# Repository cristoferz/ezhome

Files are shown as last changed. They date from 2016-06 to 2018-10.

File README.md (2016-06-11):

# ezHome Project 

This is the home for the ezHome team's development.

### Project status

For now, the project is on the beginning so there's not much to talk about.
We are developing the basis for customization capabilitys, communication standarts and somethings like that. 

More details can be founded on Issues.

## See also ##
[Project Pieces](PROJECT_PIECES.md)

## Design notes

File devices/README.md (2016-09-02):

# ezHome Project Devices
Devices are the phisical endpoints for ezHome project. Their are responsible for 
interacting with home devices like lights, light switches, doors, buzzer and so on.

Actually only one kind of device is in development, but is possible to implement
others as needed. This kind is based on Arduino devices and is capable of controlling
digital inputs and outputs. It can also be expanded to use PWM ports and Analog ports.

See also:

* [JSON Ladder Format](JSON_LADDER.md)
* [Device Communication Protocol](PROTOCOL.md)

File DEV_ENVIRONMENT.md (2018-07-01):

# Developer guide: getting your environment set up

## Web Development
1. Install node, with at least version 4.6.1
1. Run `npm install -g angular-cli` to install angular-cli
1. On folder `local-site/frontend` run `npm install`

To bring up a local server, run `ng serve`. This automatically watch for changes and rebuild. The browser should refresh automatically when changes are made.

To build the components in dev mode, run `ng build`. To build the components in release mode, run `ng build --prod`.

## Controller Development
Controller is developed is Netbeans. Install at least Netbeans 8.

Is recommended to have ant installed and on path to allow command line compilation. This is mainly necessary for a release build, for development Netbeans 
compilation will serve well.

## Database Development
EzHome database is a PostgreSQL. 

There is no templates already defined for database.  

## Devices Development
Devices are developed with Arduino IDE. Install at least version 1.6.9. 

## Build a release
Is necessary to have all environments configured. This is needed because of make commands that rebuild all structures before packaging.

```

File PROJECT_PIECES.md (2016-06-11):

# Project pieces of ezHome Project #

The ezHome Project is composed of many pieces that have to work together to the main goal. This pieces involves many different technologies so its necessary to define the bounds for each one.

This pieces are:

* **[Controller](controller/README.md)**: The main coordinator of the project, is responsible for connected every other parts. Is developed in Java SE;
* **[Local configuration site](local-site/README.md)**: Run over the controller. Is the local user interface for ezHome instalation and configuration. Is developed on Angular 2 with angular-material2. As the backend runs over the controller, it is developed on Java SE;
* **[Devices](devices/README.md)**: Are the electrical parts of the project. Mainly are used Arduinos for the job, but other device types can be accepted;
* **[Remote controlling site](remote-site/README.md)**: Is the remote web-site responsible for controlling and monitoring the home. It also controls activation and remote backups of configurations and communications with mobile platforms. It is develop on PHP and stored with postgresql;
* **[Mobile App](mobile/README.md)**: Mobile aplication for remote controlling the Home. Can communicate with remote controlling site or local configuration site, depending on used network. Is developed with ionic2;

As the project is on the beginning, the technologies are only suggestions and can change if there is a good reason for it.

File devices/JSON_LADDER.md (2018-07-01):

# JSON Ladder
JSON Ladder is the base language used to program ezHome Project compatible devices 
with the logics implemented on ezHome Project. Is basically a translation of the 
Ladder Language to a JSON format that is used for store configurations on local and remote databases.
Above is a basic example of implementation:

    { "program":
        [ { "serie": [
                { "Parallel": [
                { "serie": [
                    { "NO": 10 },
                    { "Parallel": [
                        { "serie": [
                            { "FallingEdge": 100 }
                        ] },
                        { "serie": [
                            { "RisingEdge": 101 }
                        ] }
                    ] }
                ] }
                ] },
                { "SetReset": { "address": 4, "reset": 4} }
            ] },
            { "serie": [
                { "Parallel": [
                { "serie": [
                    { "NO": 11 },
                    { "Parallel": [
                        { "serie": [
                            { "FallingEdge": 104 }
                        ] },
                        { "serie": [
                            { "RisingEdge": 105 }
                        ] }
                    ] }
                ] },
                { "serie": [
                    { "NO": 5 },
                    { "FallingEdge": 106 }
                ] }
                ] },
                { "SetReset": { "address": 2, "reset": 2} }
            ] },
        ] }

It is composed by the following parts:

## Flow tags
Flow tags are the tags used to define the interactions between the instructions on ladder engine. They do not perform any tasks on devices outputs, but define the flow of rung conditions between instructions.

## Program
The base of JSON Ladder. Its used only once on a JSON Ladder program and just define the root of the logics. Its similar to the "parallel" instructions discussed later on purpose, but is the only tag that can be used on program root.

Contains an array of series to be executed by JSON Engine.

     { "program": [ 
        { "serie": [ ... ] },
        { "serie": [ ... ] }
      ]}

## Serie
Represents a serie of instructions processed in a serial form on JSON Engine. 
Its represented by an array of instructions to processed in a serial form, each one passing a *rungCondition* to the next one and using this value on its own logics.

    { "serie": [
       { ... },
       { ... }
    ]}

## Instructions
Unlike the flow tags, instructions are intended for interactions with memory addresses, device ports or simply to interact with rungCondition to the next instruction.

Basically, every instruction receives a rungCondition and passes a new rungCondition to the next instruction. The simplest instructions are NO and NC, discussed later.

### Contact NO and NC
Contact NO and NC are the simplest instructions with input on a Ladder logics. As the ladder borns based on eletrical relays, they are representation of an eletrical switch.
NO represents a "Normally Open" switch and NC represents a "Normally Closed" switch. So the only difference between then are the inverted results, so "NO = !NC" is a good representation. 

On JSON Ladder, both contacts need an "interaction value", and this can be represented with a "boolean value".

Boolean values can be a constant value, like "true" or "false" or a representing address. As on a device an memory address can represent a phisical port or just a memory address,
Boolean Values can be used for phisical or memory interactions, allowing great flexibility to the instruction.

The constant form of a boolean value is represented by a boolean value on JSON format, as following examples:

    { "NO": true }
    { "NC": false }

Is not very logical to use constant values for contacts as the example, but boolean values are used for others purposes so its important to know that is possible.

Other way to use the boolean values are assigning to then a memory address that can be a phisical port or just a memory value. This can be done by passing the integer value of desired address, like following:

    { "NO": 0 }
    { "NC": 108 }

This assigns address 0 (normally phisical port 2) and 108 (just a memory address) to contacts.

The main objective of contact instructions are they rungCondition result. They are always based on 2 values:
* Incoming rungCondition: or the rungCondition that comes from prior instruction
* Their input value: as represented by assigned address or constant value

This way, we can represent the resulting rungCondition for NO as:

    <Incoming rungCondition> && <Input value>

And for NC as:

    <Incoming rungCondition> && !<Input value>

As you can see, the only difference is the invertion of the Input value. Incoming rungCondition always affect the resulting rungCondition the same way.

### Coil
Represents an Output on Ladder logics.

Basically, a Coil instruction reflects the incoming rungCondition on their Output Address, that can be a phisical output or memory value. The resulting rungCondition is exactly the same value as input rungCondition.
Normally Coil is the final instruction for a serie, but its not mandatory.

On JSON Ladder, Coil representation is like following:

    { "Coil": 1 }

As an coil always sets the value of their output destination, necessarily only one coil can be 
assigned to each address. This is not a restriction. If more than one coil are assigned to the 
same address, the last one on the engine flow will override their value before it reflect a 
phisical response. Probabily an unexpected behavior.

### Parallel
Parallel is a instruction, but can also be seen as an flow tag. 
It represents a *fork* on ladder logics, allowing parallel series to be executed inside a serie
and resulting *rungCondition* being united in an "or" logics.

    { "Parallel": [
       { "serie": [ ... ] },
       { "serie": [ ... ] }
    ]} 

In a "program" tag, resulting rungCondition is just discarded and next serie is initialized
with a "true" value, not affecting the next serie. On a Parallel instruction, all inner 
series resulting rungCondition are combined on a "or logics" like the following:

    serie1 | serie2 | serie3 | ...

Resulting rungCondition is passed to the next instruction on the outer serie. Following is an example of 2 Contact NO interacting with 1 Coil, using a parallel:

    { "serie": [
       { "Parallel": [
          { "serie": [
             { "NO": 1 }
          ]},
          { "serie": [
             { "NO": 2 }
          ]}
       ] },
       { "Coil": 3 }
    } 

In this example, any of the NO that have an high level, will put a high level on the Coil. 
This is because the "OR" logics of the Parallel instruction.

The series on the Parallel are the same as the series on a Program, so its possible to do anything on then, as incluing Parallel inside another Parallel. 
Is possible to use Parallel instructions on as many inner levels as necessary.       

### Edges
The edge type of instructions are the type of instruction that detects an edge on signal 
represented by rungCondition. There are 2 types of edges: Rising and Falling. They detect an 
variation on signal from high to low (FallingEge) or low to high (RisingEdge). 

The effect of such variation is a "true" value on preceding rungCondition for just on engine cycle. This is 
different from NO and NC contacts. They keep the value for as long as the signal is high or low. The edges 
just but a high level to represent the variation of the signal an just for one cycle. 
No mather what signal is before an edge, the edges only pass a high signal just one cicle when 
the expected edge is detected, turning back to low signal.

The edges have no directly output. They unique purpose is to set the preceding rungCondition as the edge is detected. 
So, they will never appear alone in a serie. There is no restriction to this, but its meaningless to do this.

The edges needs, for their internal logics, a boolean memory address. In this case, the memory address cannot be a
phisical port from device. There is no restriction to do this, but this will cause an unexpected behavior, as the port 
will interact with the internal address of the edge. The purpose of this address is to "save" the "old state" of signal
across engine cycles. This is necessary because the edge always compares the current state with the "old state", and this 
have to be saved across engine cycles.

With this is mind, there is no use for the edge address except for the edge itself.

Examples of both edge representation are the following:

    { "FallingEdge": 100 }
    { "RisingEdge": 101 }

A practical example is explore after we understand the SetReset instruction.

### SetReset
SetReset instruction are maded for, as the name says, set or reset the value of a memory address
of device. We can understand set as put "true" on this address and reset as put "false" on this 
address. Its a single instruction because its possible to define their state at runtime, inverting 
their result.

This instruction easily work in conjuction with edges, but there is no restriction to the use with others 
instructions. This instruction take 2 parameters:
* address: The output address. That the address that will be set or reset;
* reset: A boolean value that represents if the instruction will set or reset the output;

As the reset parameter is a boolean value, it can be a constant value (true or false) or a memory address
containing the expected behavior. 

An example of usage is as following:

    { "SetReset": {
       "address": 0,
       "reset": true
    }}

Or:

    { "SetReset": {
       "address": 0,
       "reset": 100
    }}    

This represents the both forms of SetReset instruction. First one use the constant form, where the value
of address 0 is always set to false when a rungCondition of true precedes the instuction. On the second form,
the value of true or false depends on value of the memory address 100. The value of the address is inverted 
accordingly to the name "reset" so, if the value of address is true (reset), the value setted is false and if
the value is false (not reset), the value setted it true.

A very useful case of use of the runtime reset value is a "auto reversing configuration". An example is as 
following:

    { "SetReset": {
       "address": 0,
       "reset": 0
    }} 

As the same address is used for both output and reset values, for every cycle that rungCondition is true the 
value of address 0 is inverted, passing from true to false or false to true. This is very useful if combined 
with an edge instruction, as the example above:

    { "serie": [
       { "NO": 1 },
       { "FallingEdge": 100 },
       { "SetReset": {
          "address": 0,
          "reset": 0
       }}
    ]} 

Consider that a push button is connected to address 1 and a LED is connected to address 0. With this configuration
for every click on the button, the light turn off or turn on and keeps this state until the next interaction with 
the button.

### NumericValues
At this point is necessary for complete understanding of the following instructions that we known a new structure:
the NumericValues. Until now, we are using just boolean values, either constants or not, but never more than this.
For the next instructions are necessary to understand that is possible to use NumericValues.

NumericValues, as the same says, are basically numbers, but we have some differences on the address system. A numeric 
address of value 18 is not the same address as a boolean address of value 18. This is because the address system for
numeric values are completely isolated for boolean addresses. This happens because of natures of values and phisical
ports of devices. Boolean address are linked to digital ports of device and Numeric address are linked to analog ports
of device. As an example, lets take the Arduino MEGA 2560. They have 54 digital ports and 16 analog ports, that are 
completely different ports. So, the boolean addresses from 0 to 52 (thats because ports 0 and 1 are useless) are linked
to the digital ports. And, the numeric addresses from 0 to 15 are linked to analog ports. The preceding addresses are 
just memory addresses, having no phisical interaction.

NumericValue have 2 forms of representation:
* Constant: having static value like above:

    { "value": 200 }

* Variable: assigned to a numeric memory address like above:

     { "address": 18 }

Once assigned to an analog port the value will reflect in the analog value for the port.

### Timers
Timers are the time based instructions for the JSON Ladder. The logics are based on 3 values, specified on definition:
* setpointValue: specifies the time in milliseconds elapsed for a timer be considered done.
* doneAddress: a boolean address that represents the done state for the timer.
* elapsedAddress: a numeric address to store the elapsed time for the timer.

With the same variables, a timer can be one of 2 types:
* TimerOn 
   
   Every time the preceding rungCondition is true the timer start counting time, until achieve the setpointValue. During 
   this time, doneAddress keeps a false value, elapsedAddress keep the time passed until the true condition and resulting
   rungCondition return false. Once the setpointValue is achieved, doneAddress gains a true value and rungCondition returns 
   true.

* TimerOff

   Every time the preceding rungCondition is true the timer start counting time, until achieve the setpointValue. During 
   this time, doneAddress keeps a true value, elapsedAddress keep the time passed until the false condition and resulting
   rungCondition return true. Once the setpointValue is achieved, doneAddress gains a false value and rungCondition returns 
   false.

If the running condition for the timer (true for TimerOn and false for TimerOff) changes, the timer resets immediatelly and 
elapsedTime returns to zero. 

An example of usage of TimerOn is as following:

    { "serie": [
       { "NO": 0 },
       { "TimerOn": {
          "setpointValue": 2000,
          "doneAddress": 1,
          "elapsedAddress": 18
       }},
       { "Coil": 2 }
    ]}
     
In this example, the contact NO commands the execution of Timer, as their control the preceding rungCondition. The Timer is 
configured for a 2s delay (2000ms), with doneAddress configured for address 1 and elapsedAddress configured for numeric 
address 18. A Coil assigned to address 2 is connected to the resulting rungCondition.

The logic is interpreted as follows:
Once the address 0 has a high value the timer will start running. During 2s the rungCondition reflects no alteration. 
If during this time the address 0 goes to an low value, the timer resets and the output will never change. Otherwise, if 
passes the 2 seconds and address 0 keeps the high value, then doneAddress will change to true and resulting rungCondition too. 
This stays like this for as long as the address 0 keeps the high value. Once the change to low value, immediatelly doneAddress 
and resulting rungCondition goes low too, no delay is applied this way.

TimerOff have a similar aproach, but with inverted values. Timer starts with a low value and reset with a high value.

Some considerations about parameters of timers:
* setpointValue can use both constants and variable values. A change during the timer execution will affect the result of timer 
without reseting him.
* doneAddress and resulting rungCondition always have the same value. Because of internal logics of the timer is necessary to 
specify an address, but is not necessary to use him.
* elapsedAddress can be used for reading, but take care with writings. A write on this address can cause unexpected behaviors. 
A mistake easy to take is try to use an address of an analog port. This will cause very strange results, and dificulty to find 
the problem. That because every cycle of engine will override the value if the analog value of the phisical port, and or the 
timer never ends, or ends very fast, depending on values of setpointValue. Anyway, of course this will not be the expected result.

### Counters
Counters are the most complex structures for now. Counters are instructions that uses the preceding rungCondition edge for autoincrement 
or autodecrement their values, according to their type (either count up or down). Their basic implementation is examplified above:

    { "Counter": {
       "countDown": false,
       "setpointValue": {
          "value": 10
       },
       "resetValue": 100,
       "doneAddress": 101,
       "countAddress": 18,
       "oneshotStateAddress": 102
    }} 

With this basics, this are the explanations about all the parameters:
* countDown: sets the timer as a count up or down. Its always a constant value so, its not possible to change at runtime.
* setpointValue: defines the value that the counter is considered "done". Explanations about what is "done" are maded above.
* resetValue: defines the boolean value that resets the counter. Can be a constant or variable
* doneAddress: boolean address that identify a counter as done. Similar to Timers this also reflects the resulting rungCondition
* countAddress: numeric address that stores the current count value.
* oneshotStateAddress: as the counters act like an edge, this is the address for the internal edge control

One simple explanation for counters is that they are an edge with a math add operation. But they do a little more than this. They 
controls a setpointValue, doneAddress and a reset operation in only one instruction. Lets explain this by parts. First of all the 
doneAddress and rungCondition. For our first example we have a count up counter (countDown: false), with a setpoint of 10. Lets put 
more instructions to be more clear:

    { "serie": [
       { "NO": 0 },
       { "Counter": {
          "countDown": false,
          "setpointValue": {
             "value": 10
          },
          "resetValue": 100,
          "doneAddress": 101,
          "countAddress": 18,
          "oneshotStateAddress": 102
       }},
       { "Coil": 1 }
    ]}  

In this example lets think we have a push button on address 0 and a LED on address 1.

At the start of program, we have the LED turn off, and the counter at 0. So, if we click 5 times on the button, nothing realy 
happens, just the internal counter goes to 5 and the LED still off. If click more 5 times, than the counter goes to 10 and 
setpointValue is hit so the rungCondition goes to true together with doneAddress and finally the LED turn on.

If at any time you read the countAddress you will have the counter value, so now we have the value of 10.

But, our LED is now turn on and there is no way to turn it off. That because differently from timers, counters do not 
autoreset at any condition. The only way to autoreset a counter is will a pulse on resetValue. If you keep the resetValue 
constantly on true, the counter will reset every cycle and never autoincrement their values.

If will implement another serie with the example above, together with our first example, will can reset your counter:

    { "serie": [
       { "NO": 2 },
       { "Coil": 100 }
    ]}

With a button connected to address 2, a click on it will reset the counter. while you keep the button pushed, the counter
never increment, they keep reseting.

### Math Operators
The counters are very useful for lots of situations, but their use is very specific as a counter. 
Sometimes is necessary to make some math operations with values. For this kind of situations there is the "MathOperation"
instruction. There 5 kind of math operations implemented by this instruction, they are (with their representation):
* ADD: +
* SUBTRACT: -
* MULTIPLY: *
* DIVIDE: /
* CHOOSE: #

They are self explanatory with the exception of the CHOOSE one. They are bettter explained above.

An example of MathOperation follows:

    { "MathOperation": {
       "type": "*",
       "operator1": {
          "address": 0
       },
       "operator2": {
          "value": 2
       },
       "resultAddress": {
          "address": 18
       }
    }}

This example shows a MathOperation with the MULTIPLY type. The result is that the value read from address 0, on operator1, 
is multiplied by 2, as the operator2 and the result is stored on numeric address 18. So the parameters explanation follows:

* type: the operator for the math operation. Can be one of: +,-,*,/,#
* operator1: a NumericValue for the first operator
* operator2: a NumericValue for the second operator
* resultAddress: a NumericAddress to store the operation result.

Math operations can use analog inputs, counters variables, timers elapsedAddress or any others numeric values as their 
operators. Is possible to use the same address on operators and resultAddress at the same instruction. One example is an
autoincrement on a numeric address, as follows:

    { "MathOperation": {
       "type": "+",
       "operator1": {
          "address": 18
       },
       "operator2": {
          "value": 1
       },
       "resultAddress": {
          "address": 18
       }
    }} 

This instruction will increment on the numeric value of address 18 every time the preceding rungCondition is true. 
But take care. The operation is done every cycle that the rungCondition is true, so if you put a NO contact before and
the user clicks the button, lots of cycle will passes during the high value of the button, incrementing the value lots 
of times. To prevent this, its common to use edges before the MathOperation, asuring that only one cycle will perform 
the operation per click.

A not self explanatory MathOperation is the CHOOSE type. But is a very simple one. Basically they choose the value to 
put on resulting address based on preceding rungCondition. If the rungCondition is false, then the operator1 value is 
putted on resultAddress, if true the value of operator2 is putted. Is a little different from the others because a edge 
will not serve well as a preceding instruction in most cases. 

The last thing to consider is the resulting rungCondition. They are not affected by MathOperation. So, if the preceding 
rungCondition is true, the resulting will be true and vice versa.

### Math Comparators
Math comparators are the "if" on Ladder logics for numeric values. Their objective is just affect the resulting 
rungCondition, not altering any memory addresses. An example of usage follows:

    { "Comparator": {
       "type": ">=",
       "value1": {
          "address": 0
       },
       "value2": {
          "value": 2
       }
    }}

Their parameter explanation follows:
* type: type of comparation. Can be one of: ==,>,>=,<,<=,!=
* value1: first value of comparation
* value2: second value of comparation

The type are all self explanatory and the logics can be read as follows:

    rungCondition = rungCondition && (value1 <type> value2)

Or as the example before:

    rungCondition = rungCondition && ([address 0] >= 2)

As you can see the operation always depends on preceding rungCondition. If they are false, the result is false and 
the instruction is not even processed. Otherwise, is processed and the result is the new rungCondition.

The example show a comparation of type >= of the value readed from address 0 (probabily an analog port) between the 
constant 2. If the value of the port is greater or equals 2, the resulting rungCondition will be true, otherwise false
respecting the preceding rungCondition too.

### External Devices
Sometimes is necessary to use external devices and sensors connected to ezHome. This devices are threated by an especific
instruction called "extDevice". Each external device has its own implementation, so theirs descriptions follow.

#### Temperature sensors
Some temperature sensor uses OneWire protocol to communicate to arduino. DS18B20 is an example of this. An example of 
instruction follows:

    { "TemperatureSensor": {
       "address": 4, 
       "idValue": "1234567890ABCDEF",
       "readDelay": { "value": 10000 },
       "elapsedAddress": 10,
       "outputAddress": 100,
       "failAddress": 5
    }}

The logics for this type of sensors is based on the following values, with explanation about each:
* address: Identifies the phisical port where the sensor is connected. In this case, is possible (and recommended) that 
many sensors are connected to the same port, but is possible to connect in other ports. In the specific case of DS18B20, 
is necessary a pull-up resistor of 4K7 to function. 
* idValue: Identifies the sensor on the bus. This value is unique per sensor, so its necessary to identify what sensor 
you are using. On the end of this session is some explanation on how to do this.
* readDelay: Specifies the delay between readings to the sensor. Other cycles assumes te last readed value. As reading 
sensor values causes some delay on whole device cycle, is recommended to reduce the reading frequency to as lower as you 
can, avoiding some interference on others logics.
* elapsedAddress: Specifies the address to keep the elapsed time between last read. Have no real use for logics.
* outputAddress: Address where readed values is stored and keeped until next read.
* failAddress: Address to indicates a fail on reading to sensor, usually because the sensor with specified address is not 
present on the port. In the case of failure, the output value will set to -127. 

The rungCondition for this instruction is true only on read cycles, as an alert of read.

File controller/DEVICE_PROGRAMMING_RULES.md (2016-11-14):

## Parts of device versions

### Version
Version is a set of modules and connections that defines the behavior of a device. Also a version is specific for a device type,
such as Arduino MEGA or UNO. This is needed because of phisical differences between then. 

### Modules
Modules is basically a group of inputs and output that defines a logic of interactions between then. This inputs and outputs
can be phisical or a connection with another module as specified above.

### Connections
As the name says, connections is the connection between different modules or different port of the same module. As a rule, 
every connection receives one, and only one, input that is always an output from a module. A connection can have multiple outputs,
that is always used as input from a module, either another or the same as the input of connection.

### Types of inputs/outputs (I/O)
There is three types of inputs/outputs that can be used in ezHome Devices:
* DIGITAL: Accepts only 2 possible values high and low, or translating to logics, is a boolean I/O;
* ANALOGIC: Is a numeric I/O, oscilating their voltage phisically and numeric value logically;
* PWM: Phisically is also a digital port, but logically is a numeric I/O. This specific type can only be used in phisical ports, 
and not on connections because they are processed by devices.

Connections also have the same type as I/Os. This is necessary because only ports of the same type can be connected. Only a 
module can "transform" an I/O from one type to another.

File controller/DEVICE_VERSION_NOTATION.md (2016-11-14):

# Device Version Notation
This document describes the programming language for ezHome devices, to be compiled and loaded on each device. 

# Modules
The main part of Device Version are the modules. Modules defines the electrical behavior and interactions between each
of his ports. All definition of a module has to be compatible with module configuration definition.

A version are a set of modules that have connections between then. 
An example of a module definition follows:

```
{
   "class": "br.com.ezhome.standard.DigitalInputModule",
   "name": "Kitchen outside door switch",
   "ports": [
      {
         "portType": "input",
         "phisicalAddress": 1
      },
      {
         "portType": "output",
         "connectionIndex": 1
      }
   ]
}
```

Above is a description of each parameter of the module.

## Class
The class attribute of a module is used by compiler to identify what module he are working on. All definition are loaded
based on class of a module.

The class is the full name of the class that defines him, as the example above:

```
"class": "br.com.ezhome.standard.modules.DigitalInputModule",
```

If the class specified on parameter is not registered a ClassNotFoundException will throws.

## Name
Name is the description of a module. This attribute is just for users to identify what module we are talking about.
The name can be any string and have no effect among the behavior of the module. An example follows:

```
"name": "Kitchen outside door switch",
```

## Ports
Ports are the inputs and outputs of a module. 

```
{
   "portType": "input",
   "phisicalAddress": 1
}
```

Ports are based on Port Types from Module Definition and can be of 2 types.

### PhisicalAddress
Are the ports connected to a phisical address of a device. The address specifies the phisical port of device. The definition
is simple and follows

```
"phisicalAddress": 1
```

Where "1" is the desired address.

### Connection
Connections, as the name says, are used to connect a module to anothers. On a module the connection is specified just by an
integer index. This is enough to create a new connection. 

```
"connectionIndex": 1
```

All module ports that use the same connectionIndex is considered connected with each other. But there's one restriction on this.

A connection can have only one input, from connection optics. From module optics, a connection INPUT is a module OUTPUT. 
This is necessary to preserve the logics of connections. If it was possible to connect two or more inputs on a single connection
the behavior of this connection will depend on the sequence of device logic cycle, something that is not controlled by the user. 

# Example
Here we have a example of a lightning controller.

```
{ 
   "modules": [ 
      {
         "class": "br.com.ezhome.standard.modules.DigitalInputModule",
         "name": "Kitchen switch",
         "ports": [
            {
               "portType": "input",
               "phisicalAddress": 0
            },
            {
               "portType": "output",
               "connectionIndex": 1
            }
         ]
      },
      {
         "class": "br.com.ezhome.standard.modules.DigitalOutputModule",
         "name": "Kitchen Light",
         "ports": [
            {
               "portType": "input",
               "connectionIndex": 3
            },
            {
               "portType": "output",
               "phisicalAddress": 3 
            },
         ]
      },
      {
         "class": "br.com.ezhome.standard.modules.LightningModule",
         "name": "Kitchen Light Controller",
         "ports": [
            {
               "portType": "input",
               "connectionIndex": 1
            },
            {
               "portType": "output",
               "connectionIndex": 3
            }
         ]
      }   
   ]
}
```

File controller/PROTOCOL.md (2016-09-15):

# ezHome Controller Communication Protocol #
## Activation and Login functions
### Validate activation
Returns activation state for this controller

    GET    /activation/validate

### Activate device
Activates controller with remote site

    POST   /activation/activate

### Login
Generates a token for access

    POST   /login/token              

----
## Serial ports
### List ports
Lists all serial ports available to controller

    GET    /config/serialPort?connected=<value>&portName=<value>

Params:

| Name | Required | Values | Description |
|---|---|---|---|
| connected | false | Boolean | Filter only ports on specified state |
| portName | false | String | Filter only specified port |

Response:

    {
        "serialPorts": [
            {
                "connected": true,
                "versionId": "0000000000000000",
                "currentOwner": "self",
                "portName": "/dev/ttyUSB0",
                "runtimeId": "0123456789ABCDEFFEDCBA9876543210",
                "deviceId": 1
            },
            {
                "connected": false,
                "portName": "/dev/ttyUSB0"
            }
        ]
    }

### Connect
Try to connect an ezHome device on port

    POST   /config/serialPort        

    { "portName": "/dev/ttyUSB0" }

Response:

    { "success": true }
    
### Disconnect   
Disconnect ezHome device on port, if available

    DELETE /config/serialPort        

### Scan
Makes a manual scan on serialPorts

    POST   /config/serialPort/scan    

### Enable/disable Auto-Scan
Enable/Disable autoscan on serial ports

    POST   /config/serialPort/autoScan 

----
## Device
### List devices
Lists configured devices

    GET    /config/device            

### Insert a new device
Insert a new device, creating a new UID

    POST   /config/device            

### Updates a device
Update device data, keeping UID

    PUT    /config/device            

### Delete a device
Inactivate device

    DELETE /config/device            

### Send command
Sends a command to device

    POST   /config/device/send

### Initializes device
Initializes device, burning firmware, creating a new UID for device and cleaning EEPROM.

    POST   /config/device/initialize 

### Upgrade firmware version
Upgrades firmware version keeping UID for device

    POST   /config/device/upgrade

### Upload program do device
Sends a program version to device

    POST   /config/device/upload     

### Config-reset
Sends a program version to device

    POST   /config/device/upload     

### Factory-reset
Resets all configs and program from device
    
    POST   /config/device/factory-reset

### Resets device
Resets device

    POST   /config/device/reset

### Pause
Pause the device logics and disable all outputs

    POST   /config/device/pause

### Resume
Resume the device logics

    POST   /config/device/resume     

### Information
Reads device information

    GET    /config/device/information

### Device-config
Reads device config

    GET    /config/device/device-config

### Read Boolean
Reads a boolean value from device

    GET    /config/device/readBoolean 

### List Models
Lists all available models of device

    GET    /config/device/model      

Response:

    {
      "models": [
         {
            "name": "Arduino MEGA 2560",
            "model_id": 2,
            "model_cod": "MEGA",
            "thumbnail": "/images/arduino_mega.jpg"
         },
         {
            "name": "Arduino NANO",
            "model_id": 3,
            "model_cod": "NANO",
            "thumbnail": "/images/arduino_nano.jpg"
         }
      ]
    }    

----
## Program
### List Programs
Lists program versions available and where they are applied

    GET    /config/device/program

### Insert Program
Creates a new version of program

    POST   /config/device/program

### Delete Program
Deletes a program version

    DELETE /config/device/program

## Devices ##
### List ###
List devices and serial ports available to the controller. Connected devices 
will return runtimeId and versionId, as a way to recognize the device independant 
of phisical port connected.  

#### Request ####
    GET /device/list
    
#### Response ####
    {
        "devices": [
            {
                "connected": true,
                "versionId": "0000000000000000",
                "currentOwner": "self",
                "name": "/dev/ttyUSB0",
                "runtimeId": "0123456789ABCDEFFEDCBA9876543210"
            },
            {
                "connected": false,
                "name": "/dev/ttyUSB0"
            }
        ]
    }

-------
### Connect ###
Connect to a device on specified serial port by **portName** parameter. 

#### Request ####
    POST /device/connect
    
    {
        "portName": "/dev/ttyUSB0"
    }
    
#### Response ####
On successfull connection:

    {
        "success": true
    }

On connection failure:

    {
        "success": false,
        "message": "gnu.io.NoSuchPortException"
    }
    
-------    
### Disconnect ###
Disconnect from device specified by **portName** parameter.

#### Request ####
    POST /device/disconnect
    
    {
        "portName": "/dev/ttyUSB0"
    }
    
#### Response ####
On successfull connection:

    {
        "success": true
    }

On connection failure:

    {
        "success": false,
        "message": "Invalid port"
    }   
    
-------
### Upload ###
Upload firmware for specified **portName**. If there is a valid
device on port, his firmware will be updated, otherwise is just
burned the new firmware.

Current configs loaded to device are preserved on proccess.

#### Request ####
    POST /device/upload
    
    { 
        "portName": "/dev/ttyUSB0",
        "model": "MEGA"
    }

#### Response ####
    {
        "result": "\navrdude: AVR device initialized and ready to accept instructions\navrdude: Device signature = 0x1e9801\navrdude: reading input file \"/tmp/ezHome-2103596859514401669.hex\"\navrdude: writing flash (20666 bytes):\navrdude: 20666 bytes of flash written\navrdude: verifying flash memory against /tmp/ezHome-2103596859514401669.hex:\navrdude: load data flash data from input file /tmp/ezHome-2103596859514401669.hex:\navrdude: input file /tmp/ezHome-2103596859514401669.hex contains 20666 bytes\navrdude: reading on-chip flash data:\navrdude: verifying ...\navrdude: 20666 bytes of flash verified\n\navrdude done.  Thank you.\n\n",
        "success": true
    }
    
------
### Send ###
Sends a **command** to especified **portName** and gets the result.

#### Request ####
    POST /device/send
    
    { 
        "portName": "/dev/ttyUSB0",
        "command": "runtime-id"
    }
    
#### Response ####
    {
       "success": true,
       "result": "RuntimeId=00000000000000000000000000000000"
    }
    
------

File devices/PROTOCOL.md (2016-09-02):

# Devices Communication Protocol for ezHome Project
This document provides protocol definition for devices used on ezHome Project. 
This protocol will be used on communications via serial port between devices and ezHome Controller.

## Table of contents
1. [Communication Standards](#markdown-header-communication-standards)
    1. [Send messages](#markdown-header-send-messages)
    1. [Received Messages](#markdown-header-received-messages)
1. [Query Functions](#markdown-header-query-functions)
    1. [Information](#markdown-header-information-query)
    1. [Device Config](#markdown-header-device-config-query)
    1. [Status](#markdown-header-status-query)
    1. [RuntimeId](#markdown-header-runtimeid-query)
    1. [VersionId](#markdown-header-versionid-query)
    1. [Read Boolean](#markdown-header-read-boolean)
    1. [Read Numeric](#markdown-header-read-numeric)
1. [Command Functions](#markdown-header-command-functions)
    1. [Factory Reset](#markdown-header-factory-reset)
    1. [Config Reset](#markdown-header-config-reset)
    1. [Config Output](#markdown-header-config-output)
    1. [Config PWM](#markdown-header-config-pwm)
    1. [Start](#markdown-header-start)
    1. [Stop](#markdown-header-stop)
    1. [Write Boolean](#markdown-header-write-boolean)
    1. [Write Numeric](#markdown-header-write-numeric)
1. [Program Functions](#markdown-header-program-functions)
    1. [Program Function Steps](#markdown-header-program-function-steps)

----    

## Communication Standards 
Messages of communication protocol have 2 types:
1. Send messages
1. Received messages

### Send Messages
These are the messages sended from controller to device. Every sended message waits for a response, 
confirming that sended command is executed.

They have 2 main formats:
* Normal messages: are the most common messages between both parts. 
Basically are a single line command preceded by a <End-Of-Line> character. Ex.:

       runtime-id 

* Programming messages: This special type of message is designed to be used only for device programation. 
This is necessary because of nature of sended data, as they are binary and cannot respect the format of a basic message. 
These messages are better described above.

### Received Messages
These are the messages sended from device to controller. There are 2 kinds of this messages:
* Response messages: this is a response to a sended message or command. 
As the messages can have many lines, every response message have a finish string. This finish string is a line with only **EOM**.

Example of response message:

    RuntimeId=1234567890876542
    EOM
    
* Status messages: this are the messages sended from device to controller to report an event that occurs on 
device that is not a response to a sended message. An example is a port state that can vary based on a light switch.
This kind of message are always single-lined, so there's no need of a finish string.

Example of status message:

    IS=1
    
## Query Functions
Query are operations used to query informations from device. Informations can be states of addresses, 
number of ports, runtimeId, version etc.

### Information query
Information returns data about loaded firmware, protocol version and available space on device to be 
used by the program.

Example of information request:

    information
    
Example of response:

    ezHome=0.1
    Protocol Version=1.0
    Booleans=1024
    Numerics=96
    Strings=0
    Max Program Size=3750
    Current Program Size=50
    EOM

This examples is a response from an Arduino Mega device. It is composed of several parts. They are:
* ezHome: indicates the firmwareVersion of ezHome device.
* Protocol Version: are the protocol version used by this device. 
Generally this are compatible with firmwareVersion
* Booleans: Number of boolean variables that can be used on this device
* Numerics: Number of numeric variables that can be used on this device
* String: Number of string variables that can be used on this device
* Max Program Size: returns that maximum program size that can be loaded on this device. 
It depends directly on EEPROM size of device.
* Current Program Size: return the size of current program loaded on device.
* EOM: the finish string

### Device Config Query
Device config query returns the device model and actual port configurations for this device. 

Example of request:

    device-config
    
Partial example of response:
    
    Device Name=Arduino
    pin2, 0, output
    pin3, 1, output
    pin4, 2, input
    ...
    pin53, 51, input
    A0, 0, analogInput
    A1, 1, analogInput
    ...
    A15, 15, analogInput
    EOM

This is a response from an Arduino Mega device. This response is composed of following parts:
* Device Name: Returns the device name
* Digital ports: Current configuration for digital ports. Are composed of 3 parts
    1. pin**X**: identifies the phisical pin on arduino
    1. address: represents the address (integer) used to access the state of this port
    1. mode: current mode defined for this port. Can be *input*, *output* or *pwm*. 
Analog ports can be *analogInput* or *analogOutput*
* EOM: finish string

### Status query
Status query function returns if the device is running or paused.
Devices can paused their engine by command.

Example of request:

    status
    
Example of response:

    Running=true
    EOM
    
### RuntimeId query
RuntimeId is the unique identification number for a device. Is used by controller to know on what 
serial port each device is connected and to control what versions can be used.
This information is also included on startup message.

Example of request:

    runtime-id
    
Example of response:

    RuntimeId=0123456789ABCDEFFEDCBA9876543210
    EOM
    
### VersionId query
VersionId is the unique identification number for a program version loaded into a device. 
This can assures that a expected version of program is loaded on device. Every program version
must create a new unique versionId.

Example of request:

    version-id
    
Example of response:

    RuntimeVersionId=0123456789ABCDEFFEDCBA9876543210
    EOM
    
### Read Boolean
Reads boolean state for given address on device. Address can be a port address or memory addresses. 

Example of request:

    read b 5
    
Example of response:

    1
    EOM
    
This response indicates that the address 5, which in this case is port 3, has a high level.

### Read Numeric
No numeric implementations are ready yet.

## Command Functions
Command functions are used to interact with device, changing states of addresses, port modes etc.

### Factory Reset
Factory reset is a master reset function for device. It cleans program and resets modes of all ports.
It also cleans RuntimeId and VersionId, so device loses its references.

Example of request:

    factory-reset
    
Example of response:
    
    Success=true
    EOM
    
### Config Reset
Config reset restore all ports to their initial states. 
Initial states of digital ports are Input mode and on analog are analogInput mode. 
Config-reset is actually the only way to change a port from output mode to input mode.

Example of request:

    config-reset
    
Example of response:

    Success=true
    EOM
    
### Config Output
Config output command defines a port as output. This configuration is writed on EEPROM, 
so it can only be changed by config-reset command.

Example of request:

    config-output 2
    
Example of response:

    Success=true
    EOM
    
This request configures phisical pin 2 on arduino to be an output port.

### Config PWM
Config PWM command defines a port as PWM Output. 

Example of request:

    config-pwm 4
    
Example of success response:

    Success=true
    EOM
    
Example of error response:
    
    Error=Not a valid PWM pin: 4
    EOM
    
As not all ports from a device can be configured as a PWM output an error can be throw if a invalid
port is given.    

### Start
Start command controls the running state of device engine. As the name suggests, it start the engine 
processing and the logics of program will be applied. Ports will respect the logics of the program.

Example of request:

    start
    
Example of response:
   
    Success=true
    EOM
    
### Stop
Stop command controls the running state of device engine. As the name suggests, it stops the engine 
processing and the logics of program will not be applied. All outputs are put on LOW state.

Example of request:

    stop
    
Example of response:
   
    Success=true
    EOM
    
### Write Boolean
Write boolean command function set a boolean value to specified address. 

Example of request:

    write b 2 1
    
Example of response:

    EOM
    
This request sets the boolean value of address 2 (in this case is pin 4 of arduino) to be at high level.     

Ps.: *This function cannot assure that this value will be preserved, just sets the current state. 
This could be overwriten by program engine on the next running cycle so realy works on 
address that are designed to be externally seted.*

### Write Numeric
No numeric implementations are ready yet.

## Program Functions
Program functions are specifically designed for program upload to device. There are 2 types of program
function:
* Download: Sends program to device, stoping engine. This function stops the engine at download beginning and starts at 
the end, so the ports can switch states during proccess
* Patch: Sends program to device, without stoping engine. This function download the new program without 
stoping the engine, so there's a risk of anomalous behaviors on big program changes.

### Program Function Steps
As the program function are more complex, their are composed of 2 pairs of request/response, as described
above:

**Header message:** informs to device the size of the program that will be send. This prepared the device
to receive full program;

Example of request:
    
    download 50
    
Response:

    Success=true
    Bytes=50
    EOM
    
This confirms that 50 bytes will be sended.

**Body message:** Transmits the program itself. As the total bytes is defined by header message the device
reads the amount of bytes specified putting directly into program memory. At the end the program is writen
on device EEPROM. 

The format used to send the program to device is based on [JSON Ladder format](JSON_LADDER.md) and its convertion to binary format is better described [here](JSON_LADDER_BINARY_CONVERSION.md).

Response:

    Success=true
    Bytes=50
    EOM
    
This confirms that the 50 bytes specified by program is received and writed on device's EEPROM.

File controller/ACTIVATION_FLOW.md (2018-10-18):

# ezHome Controller activation flow
This flow describes the process of activation for each controller and the security protocol used for comunication with remote server asuring maximum security for both sides.

## Local private and public key
The first step after instalation of ezHome controller is the generation of public and private keys. This is done internally by ezHome Security Manager and
this keys are stored only locally with the controller. The private key can never be transmited to another device, as this can destroy all the security process. 
Public keys are transmitted as needed.

## Certificate Signing Request (CSR)
After the generation of keys, next is to generate the CSR or Certificate Signing Request. This is needed for ezHome remote servers generate a certificate.
This request includes data about your controller and necessary keys for the certificate generation. 

## ezHome CA (Certificate Authority)
The ezHome CA is the main Certication Authority responsible for all controller certificates. This is de CA for all certificates generated by CSRs transmitted.

## Certificate generation
The CSR are now transmitted to ezHome remote servers and the servers are responsible for the generation of a secure and unique certificate that will be returned.
After that, the controller is just identified by its certificate and no other data is necessary.

## Communications
After all process done, all communications between controller and ezHome remote server are done via SSL (https) using both server and client certificates, based on 
ezHome CA. This asures criptografic data.

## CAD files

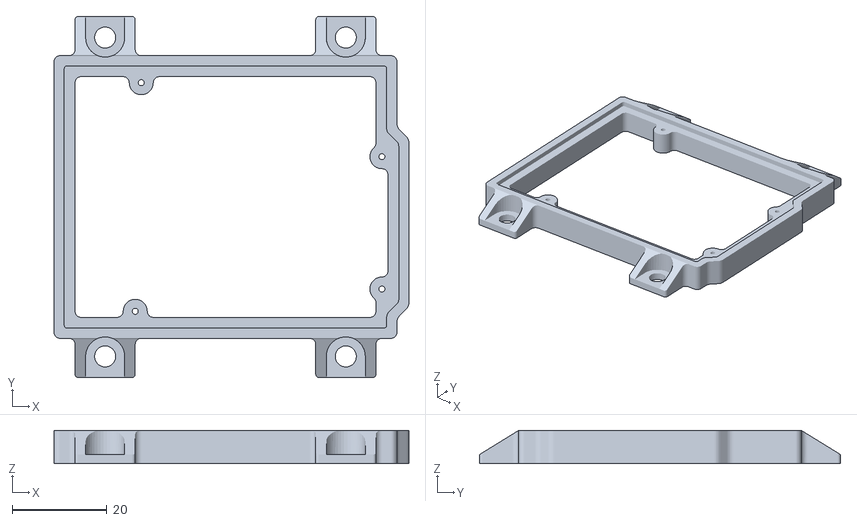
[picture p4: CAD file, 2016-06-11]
hardware/boxes/raspberry/UNO_R2_MOUNT.STL
74.9 x 76.2 x 6.99

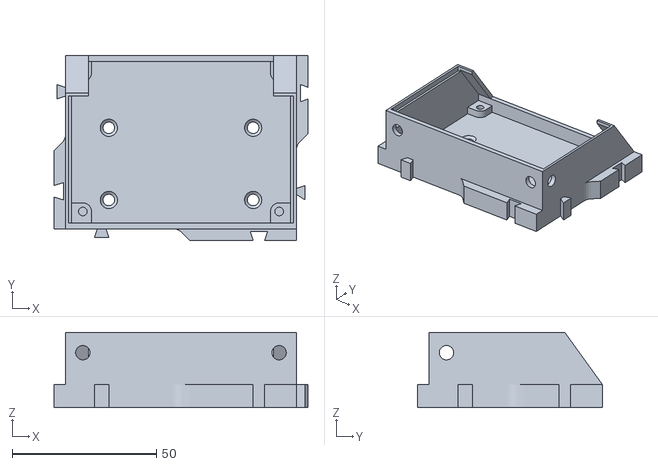
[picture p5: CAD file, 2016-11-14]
hardware/boxes/Relays/SupportV3-Box.stl
88.0 x 64.0 x 26.0

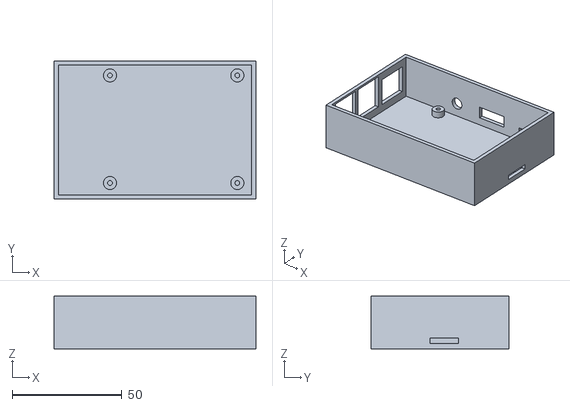
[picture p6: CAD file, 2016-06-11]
hardware/boxes/v1/test/teste02.stl
92.0 x 63.0 x 24.0

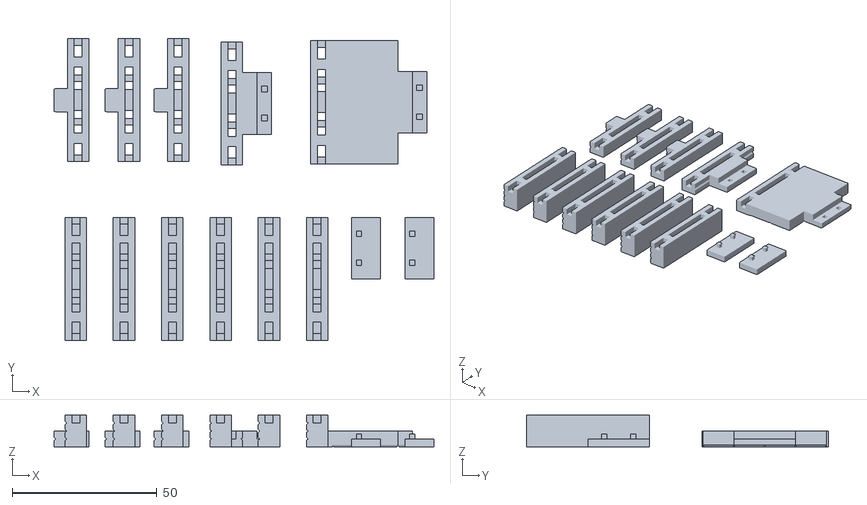
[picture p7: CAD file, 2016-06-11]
hardware/maquete/Beams_002.STL
131.1 x 104.2 x 11.0

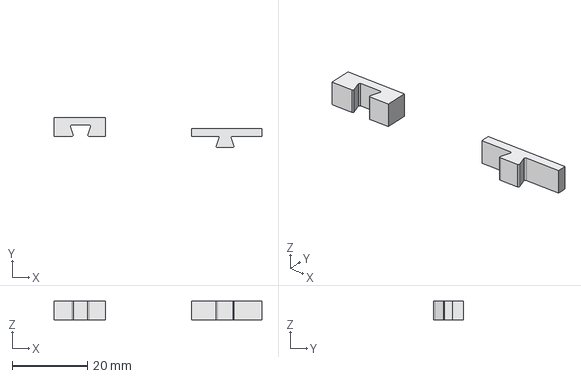
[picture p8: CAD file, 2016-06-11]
hardware/boxes/Parts/Encaixe.fcstd
55.3 x 8.00 x 5.00 mm

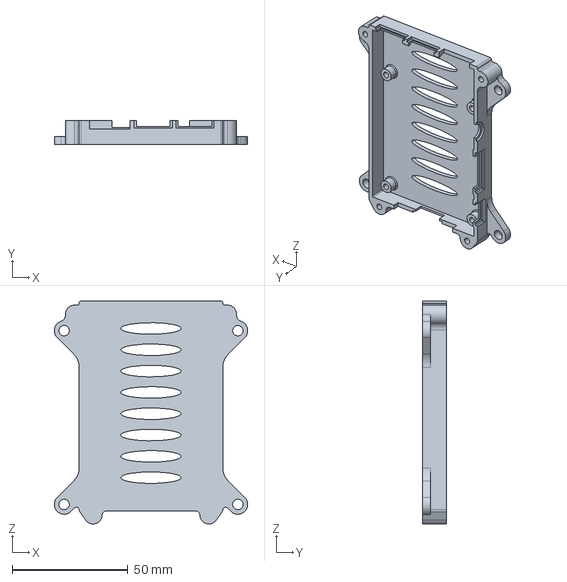
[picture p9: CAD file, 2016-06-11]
hardware/boxes/raspberry/rpi2-bottom.stp
83.5 x 10.3 x 96.2 mm

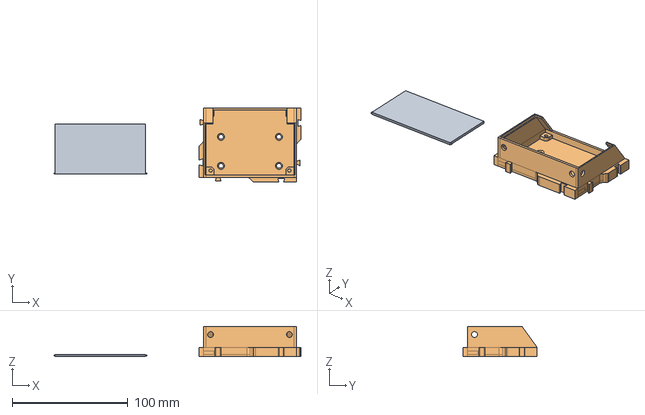
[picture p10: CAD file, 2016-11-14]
hardware/boxes/Relays/SupportV3.fcstd
213.0 x 64.0 x 26.0 mm
Tampa

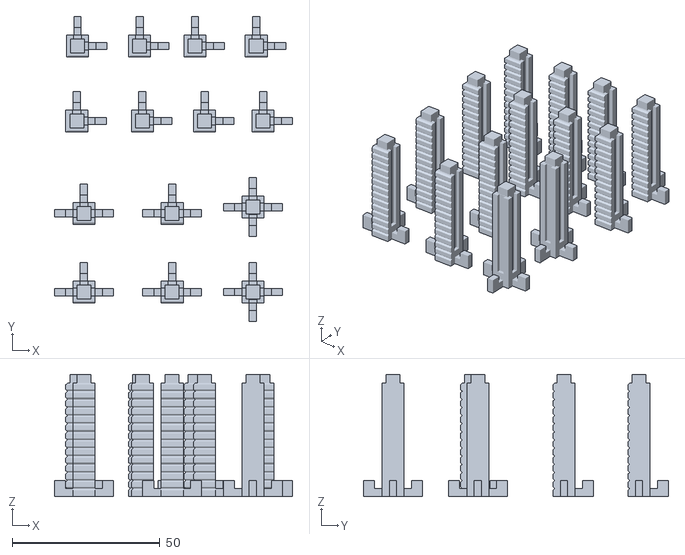
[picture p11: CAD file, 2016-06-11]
hardware/maquete/Columns_001.STL
80.8 x 103.3 x 41.5

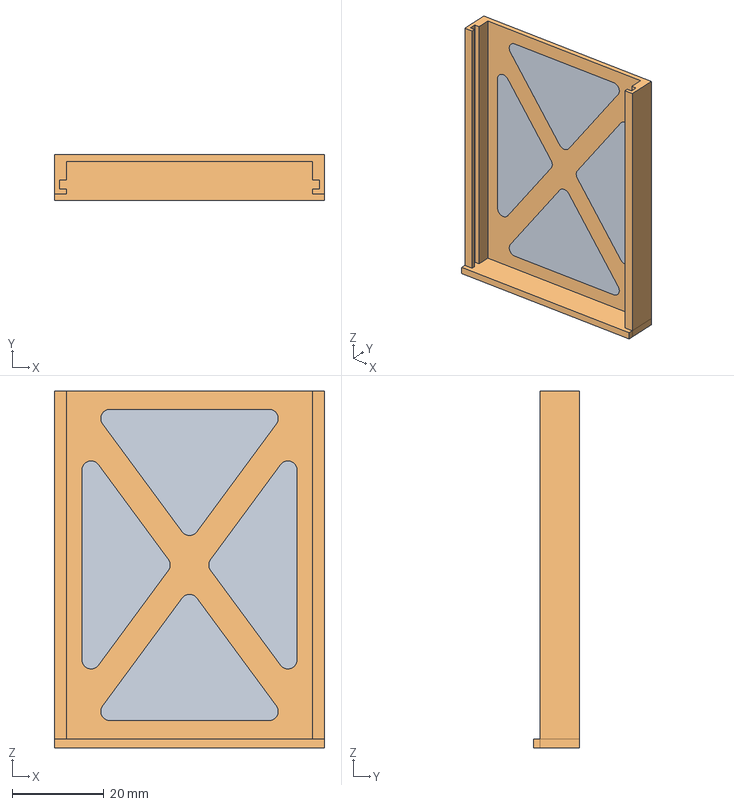
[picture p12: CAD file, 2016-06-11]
hardware/boxes/Parts/Relays.fcstd
59.0 x 10.0 x 78.0 mm
4 Relay

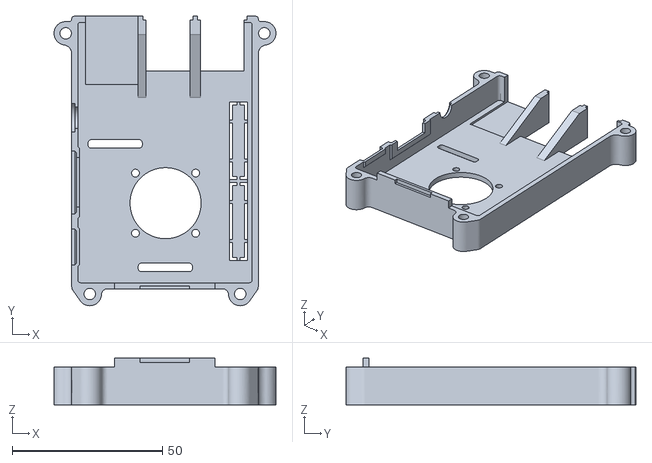
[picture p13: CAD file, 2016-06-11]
hardware/boxes/raspberry/rpi2-top_25mm-fan_netfabb.stl
73.8 x 96.2 x 15.5

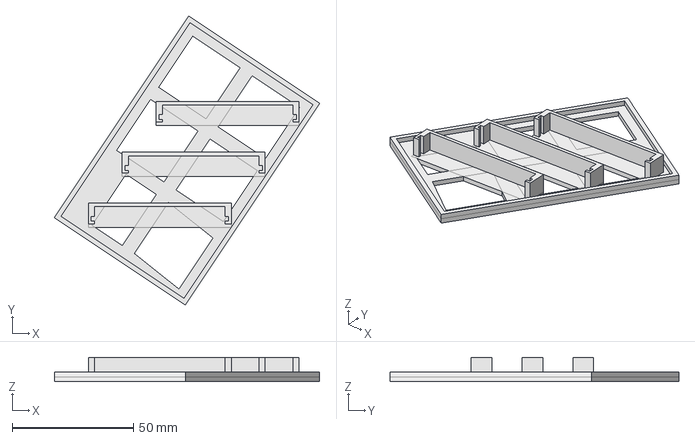
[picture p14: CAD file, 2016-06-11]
hardware/boxes/Relays/DoubleRelay.fcstd
109.6 x 119.3 x 10.0 mm

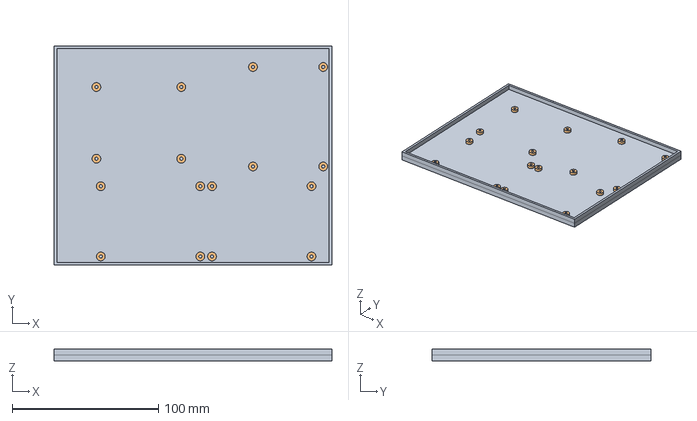
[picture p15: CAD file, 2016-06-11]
hardware/boxes/v1/test/Test01.fcstd
190.0 x 150.0 x 8.00 mm

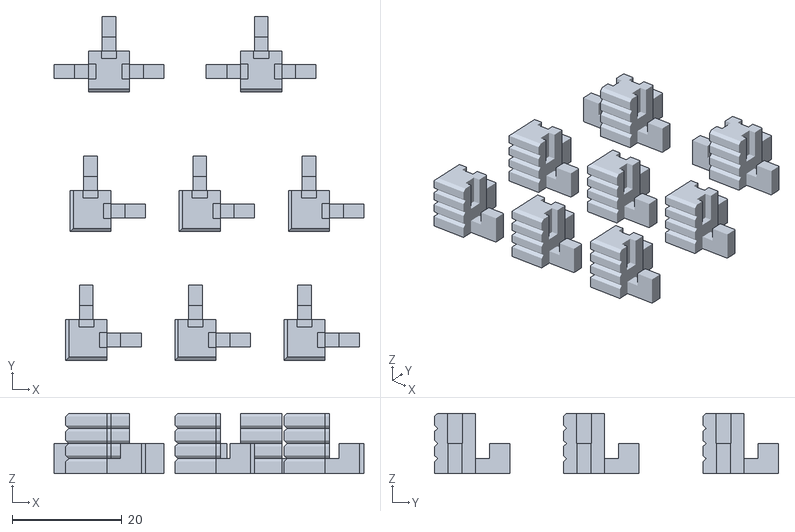
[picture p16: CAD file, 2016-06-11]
hardware/maquete/Caps_001.STL
56.3 x 62.5 x 11.0

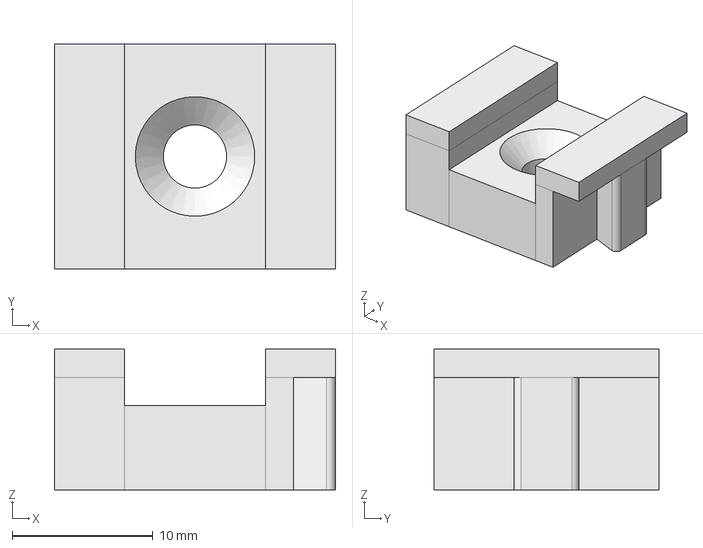
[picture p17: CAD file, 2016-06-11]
hardware/boxes/Parts/Encaixe-Parafuso.fcstd
20.0 x 16.0 x 10.0 mm

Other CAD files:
hardware/boxes/v1/test/test02.fcstd
hardware/boxes/raspberry/Raspberry_Pi_B+_Sleeve_v1-1_SOLID.STL
hardware/boxes/Relays/SupportTest2.stl
hardware/maquete/Roof_002.STL
hardware/boxes/Parts/Base.fcstd
hardware/boxes/Parts/Encaixe-Parafuso.stl
hardware/boxes/Parts/socket-screw.stl
hardware/boxes/Relays/4-Relay-Box.stl
hardware/boxes/Relays/4-Relay-Cover.stl
hardware/boxes/Relays/Engate teste.stl
hardware/boxes/Relays/SupportModel0.stl
hardware/boxes/Relays/SupportTest.fcstd
hardware/boxes/Relays/SupportTest.stl
hardware/boxes/Relays/SupportV1.fcstd
hardware/boxes/Relays/SupportV1.stl
hardware/boxes/Relays/SupportV2.fcstd
hardware/boxes/Relays/SupportV3-Tampa.stl
hardware/boxes/raspberry/MEGA_R2_MOUNT.STL
hardware/boxes/raspberry/Raspberry_Pi_B+_Sleeve_v1-1_CAP.STL
hardware/boxes/raspberry/Raspberry_Pi_B+_Sleeve_v1-1_VENTED.STL
hardware/boxes/raspberry/rpi2-bottom_100mm-vesa_netfabb.stl
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

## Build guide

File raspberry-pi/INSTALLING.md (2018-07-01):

# Raspberry Pi Installation
Raspberry Pi is the most recommended server for use with ezHome. That's because Raspberry Pi is smaller and cheaper than 
a normal computer and can easily be installed phisically together with arduino and other electrical parts of the project. 

But, there's no problem to use another kind of hardware for the project. Raspberry is only recommended, but not mandatory. 
This manual focus on the process of Installation of a clean Raspberry Pi, based on Raspbian OS. 

## Requirements
For innital configuration of Raspberry Pi you will need the following:
* HDMI device to use as monitor for Raspberry Pi. Can be a TV or a PC monitor
* A USB Keyboard connected to any USB port of Raspberry Pi
* A network connection for your Pi. Older versions only support cable connections, but new ones can use wifi connection 

## Installing OS
This process is basically follow the instructions on (Raspberry Pi Official Website)[https://www.raspberrypi.org/documentation/installation/installing-images/] 
for installation of Raspbian OS. It's possible also to install NOOBS first and than change to raspbian. The most important is to have
the Raspberry Pi installed with Raspbian.

## Configuring Network
Next step is to configure the network of raspberry. On most environments network is auto-configured (via DHCP), but is necessary
for us to take the assigned IP for future uses. This can be done by issuing the following command:

```
pi@raspberrypi:~ $ ifconfig
eth0      Link encap:Ethernet  HWaddr b8:27:eb:5e:cf:65  
          inet addr:192.168.1.16  Bcast:192.168.1.255  Mask:255.255.255.0
          inet6 addr: fe80::8f35:15ad:b593:a02c/64 Scope:Link
          UP BROADCAST RUNNING MULTICAST  MTU:1500  Metric:1
          RX packets:1308 errors:0 dropped:2 overruns:0 frame:0
          TX packets:384 errors:0 dropped:0 overruns:0 carrier:0
          collisions:0 txqueuelen:1000 
          RX bytes:229929 (224.5 KiB)  TX bytes:41889 (40.9 KiB)

lo        Link encap:Local Loopback  
          inet addr:127.0.0.1  Mask:255.0.0.0
          inet6 addr: ::1/128 Scope:Host
          UP LOOPBACK RUNNING  MTU:65536  Metric:1
          RX packets:329 errors:0 dropped:0 overruns:0 frame:0
          TX packets:329 errors:0 dropped:0 overruns:0 carrier:0
          collisions:0 txqueuelen:1 
          RX bytes:31906 (31.1 KiB)  TX bytes:31906 (31.1 KiB)

```

The information that we need is the "inet addr: " for the eth0 interface. On our example is "192.168.1.16".

## Adding ezHome APT Repository and installing ezHome
First step on installation of ezHome is the configuration of APT repository. This will make easier to install 
and update ezHome with newer versions. To do this you need to login on raspberry and type the following commands:
```
echo "deb http://ec2-52-67-166-196.sa-east-1.compute.amazonaws.com/repository/ binary/" | sudo tee -a /etc/apt/sources.list.d/ezhome.list
sudo apt-get update
sudo apt-get install ezhome 
```

The output will be something like the following

```
pi@raspberrypi:~ $ sudo apt-get install ezhome 
Reading package lists... Done
Building dependency tree       
Reading state information... Done
The following extra packages will be installed:
  libpq5 librxtx-java libxi6 libxrender1 libxtst6 oracle-java8-jdk postgresql-9.4 postgresql-client-9.4 postgresql-client-common postgresql-common ssl-cert x11-common
Suggested packages:
  oidentd ident-server locales-all postgresql-doc-9.4 openssl-blacklist
The following NEW packages will be installed:
  ezhome libpq5 librxtx-java libxi6 libxrender1 libxtst6 oracle-java8-jdk postgresql-9.4 postgresql-client-9.4 postgresql-client-common postgresql-common ssl-cert x11-common
0 upgraded, 13 newly installed, 0 to remove and 26 not upgraded.
Need to get 68.2 MB of archives.
After this operation, 196 MB of additional disk space will be used.
Do you want to continue? [Y/n] y
WARNING: The following packages cannot be authenticated!
  ezhome
Install these packages without verification? [y/N] y
```
After that, ezHome libraries will be installed successfully.

Ps.: Is normal to see the message

```
WARNING: The following packages cannot be authenticated!
  ezhome
```

That's because ezHome .deb package is not signed (we are working on this...). 

## Innitializing ezHome Database

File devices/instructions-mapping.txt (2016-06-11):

000
001
010
011
10000
10001
10010
10011
10100
10101
10110
10111
11000
11001
11010
11011
11100
11101
1111000
1111001
1111010
1111011
1111100

1111101 0x7D
1111110 0x7E

11111111

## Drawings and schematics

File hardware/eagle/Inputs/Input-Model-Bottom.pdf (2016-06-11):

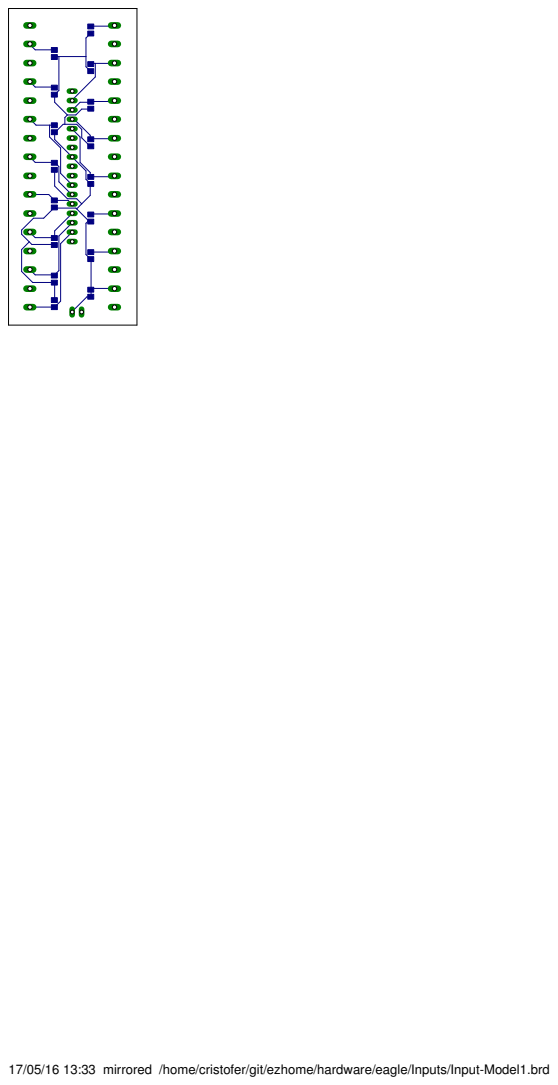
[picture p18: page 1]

17/05/16 13:33 mirrored /home/cristofer/git/ezhome/hardware/eagle/Inputs/Input-Model1.brd

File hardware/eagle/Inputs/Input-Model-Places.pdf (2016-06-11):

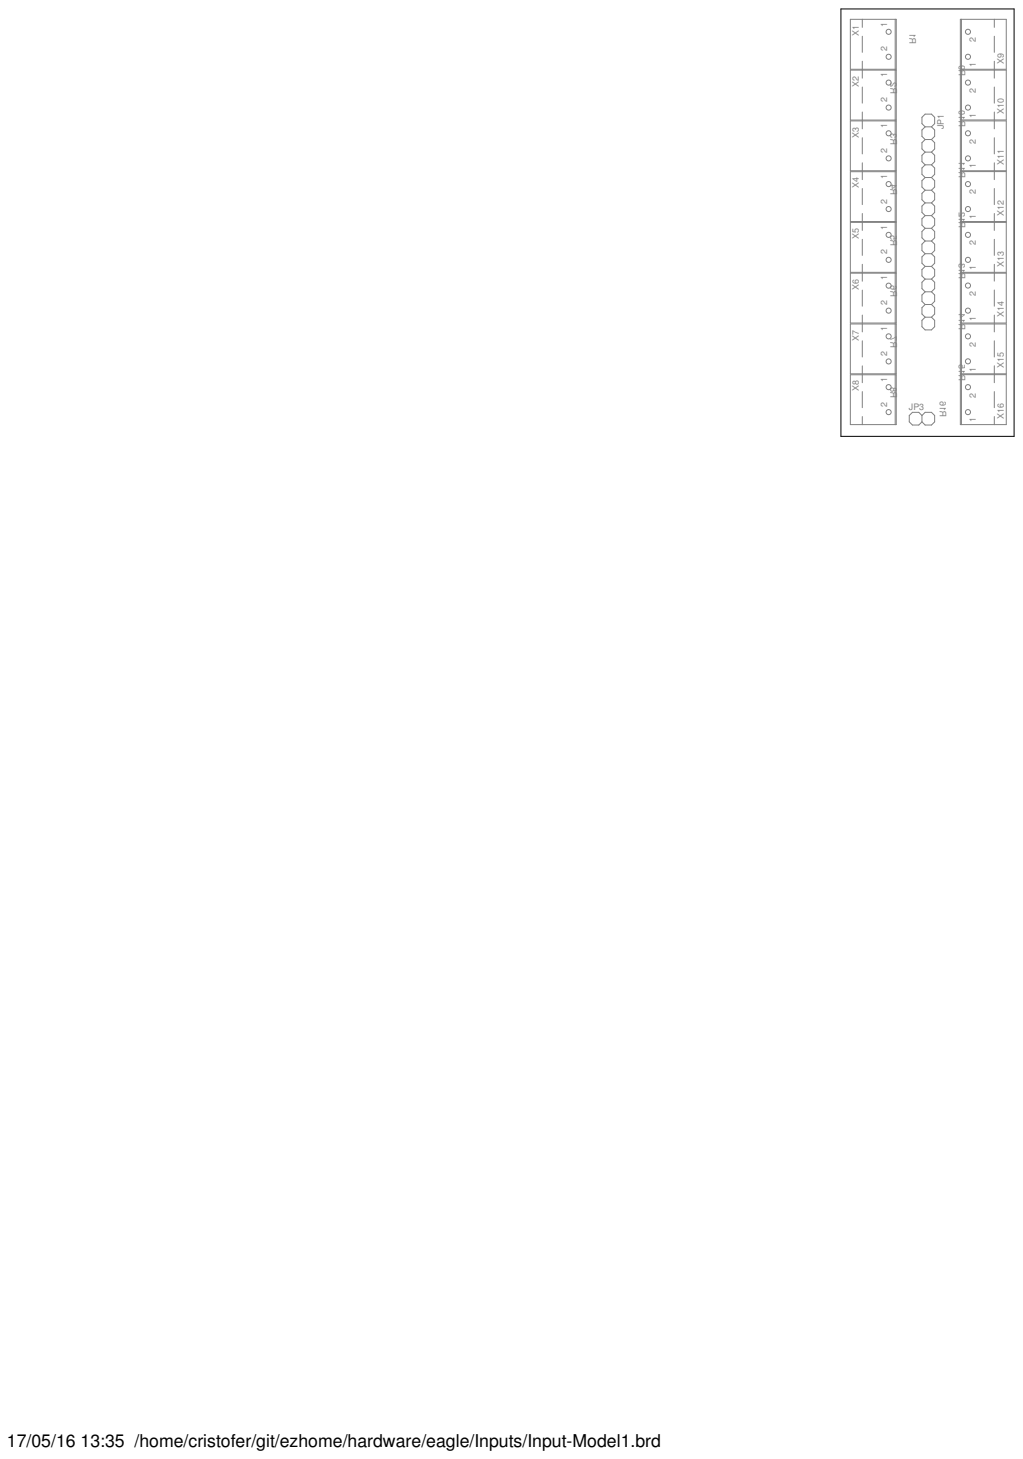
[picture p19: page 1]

17/05/16 13:35 /home/cristofer/git/ezhome/hardware/eagle/Inputs/Input-Model1.brd

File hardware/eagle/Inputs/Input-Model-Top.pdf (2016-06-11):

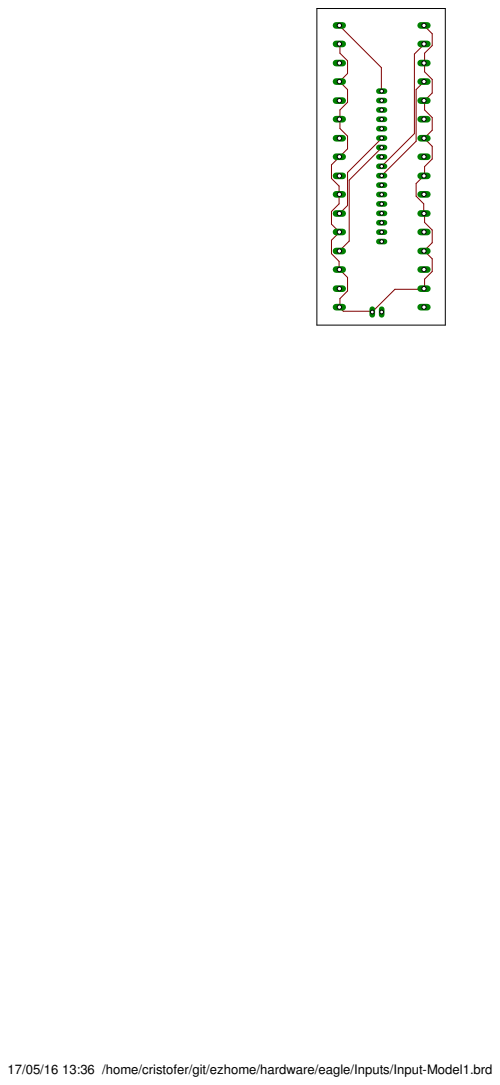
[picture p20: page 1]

17/05/16 13:36 /home/cristofer/git/ezhome/hardware/eagle/Inputs/Input-Model1.brd

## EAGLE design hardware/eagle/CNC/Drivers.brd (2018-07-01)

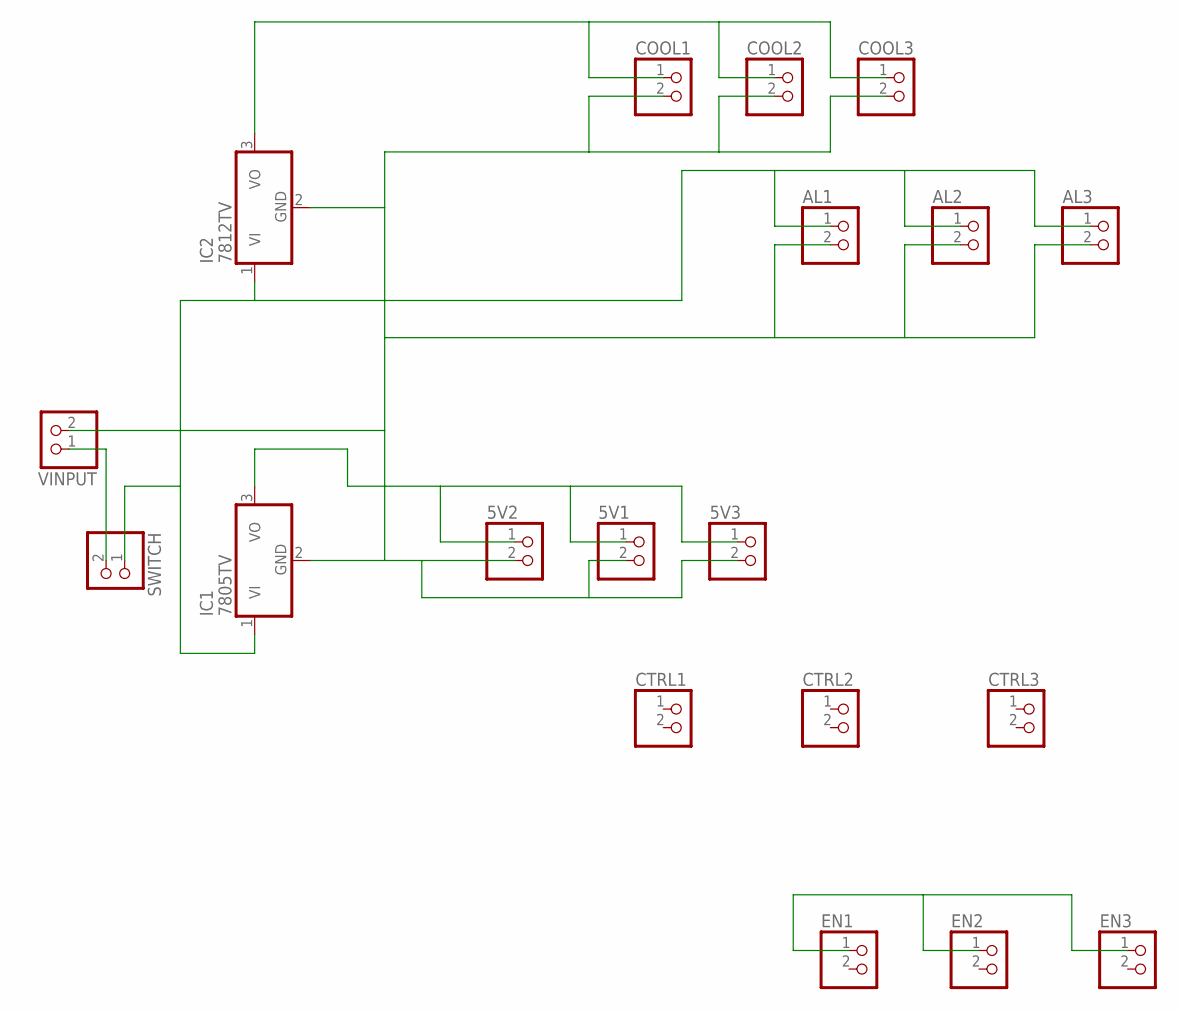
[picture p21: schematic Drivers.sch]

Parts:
5V1, 5V2, 5V3: PINHD-1X2; 1X02
AL1, AL2, AL3: PINHD-1X2; 1X02
COOL1, COOL2, COOL3: PINHD-1X2; 1X02
CTRL1, CTRL2, CTRL3: PINHD-1X2; 1X02
EN1, EN2, EN3: PINHD-1X2; 1X02
IC1: 7805TV; TO220V
IC2: 7812TV; TO220V
SWITCH: PINHD-1X2; 1X02
VINPUT: PINHD-1X2; 1X02

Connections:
unnamed: 5V1.2, 5V2.2, 5V3.2, AL1.2, AL2.2, AL3.2, COOL1.2, COOL2.2, COOL3.2, IC1.2 (GND), IC2.2 (GND), VINPUT.2
unnamed: 5V1.1, 5V2.1, 5V3.1, IC1.3 (VO)
unnamed: EN1.1, EN2.1, EN3.1
unnamed: AL1.1, AL2.1, AL3.1, IC1.1 (VI), IC2.1 (VI), SWITCH.1
unnamed: SWITCH.2, VINPUT.1
unnamed: COOL1.1, COOL2.1, COOL3.1, IC2.3 (VO)

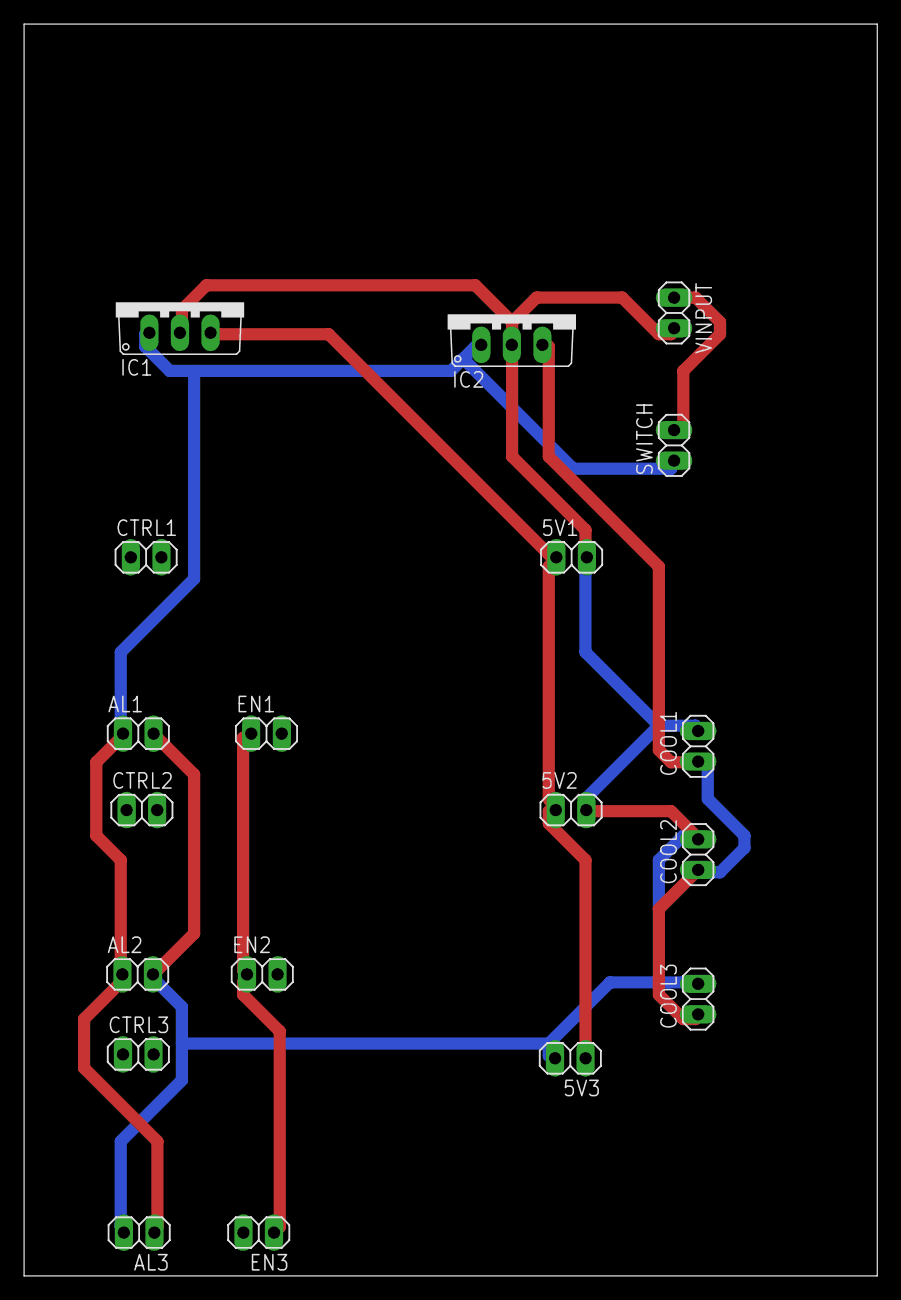
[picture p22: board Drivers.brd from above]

Board: 2 copper layers, 70.9 x 104.0 mm, 19 parts (0 on the bottom side), 6 nets.

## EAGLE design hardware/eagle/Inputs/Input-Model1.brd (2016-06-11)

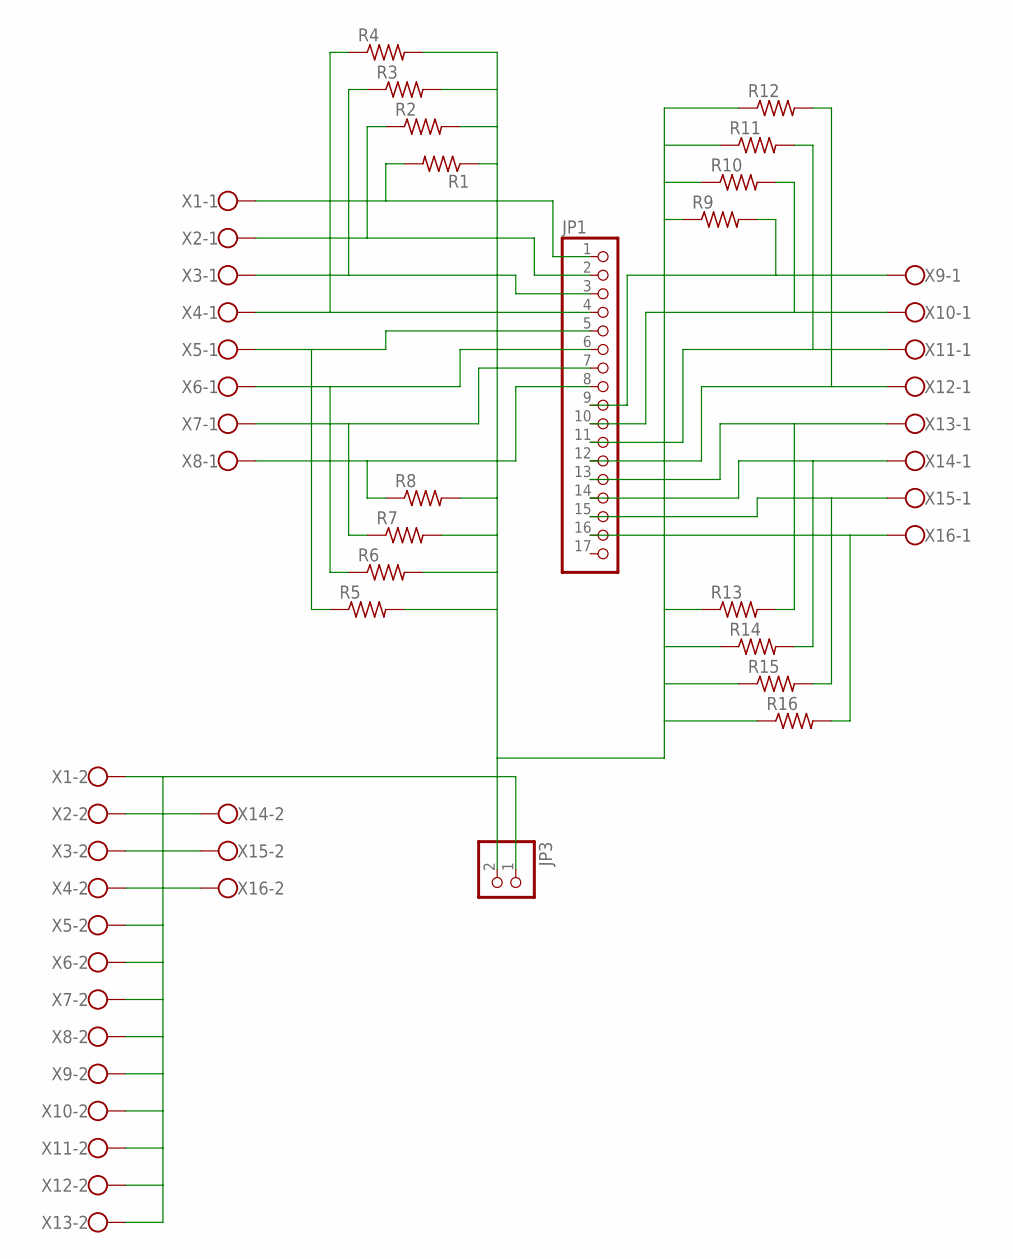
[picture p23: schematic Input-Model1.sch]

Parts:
JP1: PINHD-1X17; 1X17
JP3: PINHD-1X2; 1X02
R1, R2, R3, R4, R5, R6, R7, R8, R9, R10, R11, R12, R13, R14, R15, R16: R-US_M0805; M0805
X1, X2, X3, X4, X5, X6, X7, X8, X9, X10, X11, X12, X13, X14, X15, X16: W237-102

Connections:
unnamed: JP1.1, R1.2, X1.1
unnamed: JP1.8, JP3.2, R1.1, R2.2, R3.2, R4.2, R5.2, R6.2, R7.2, R8.1, R8.2, R9.1, R10.1, R11.1, R12.1, R13.1, R14.1, R15.1, R16.1, X8.1
unnamed: JP3.1, X1.2, X2.2, X3.2, X4.2, X5.2, X6.2, X7.2, X8.2, X9.2, X10.2, X11.2, X12.2, X13.2, X14.2, X15.2, X16.2
unnamed: JP1.2, R2.1, X2.1
unnamed: JP1.3, R3.1, X3.1
unnamed: JP1.4, R4.1, X4.1
unnamed: JP1.5, R5.1, X5.1
unnamed: JP1.7, R7.1, X7.1
unnamed: JP1.6, R6.1, X6.1
unnamed: JP1.16, R16.2, X16.1
unnamed: JP1.9, R9.2, X9.1
unnamed: JP1.10, R10.2, X10.1
unnamed: JP1.11, R11.2, X11.1
unnamed: JP1.12, R12.2, X12.1
unnamed: JP1.13, R13.2, X13.1
unnamed: JP1.14, R14.2, X14.1
unnamed: JP1.15, R15.2, X15.1

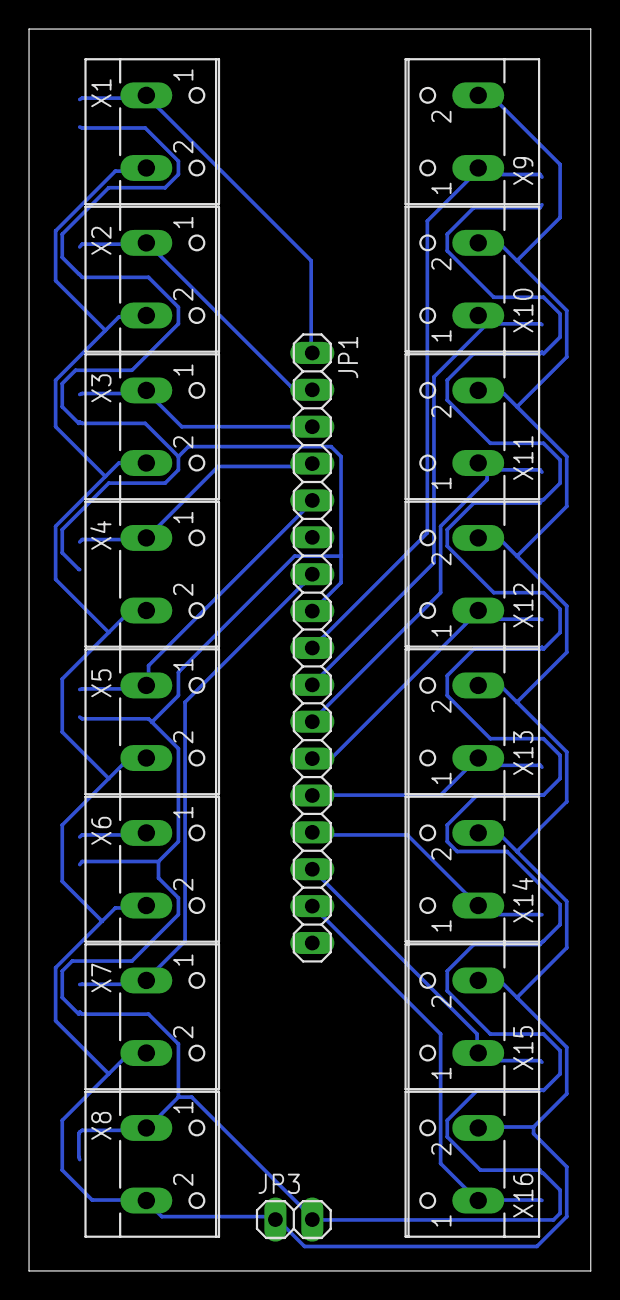
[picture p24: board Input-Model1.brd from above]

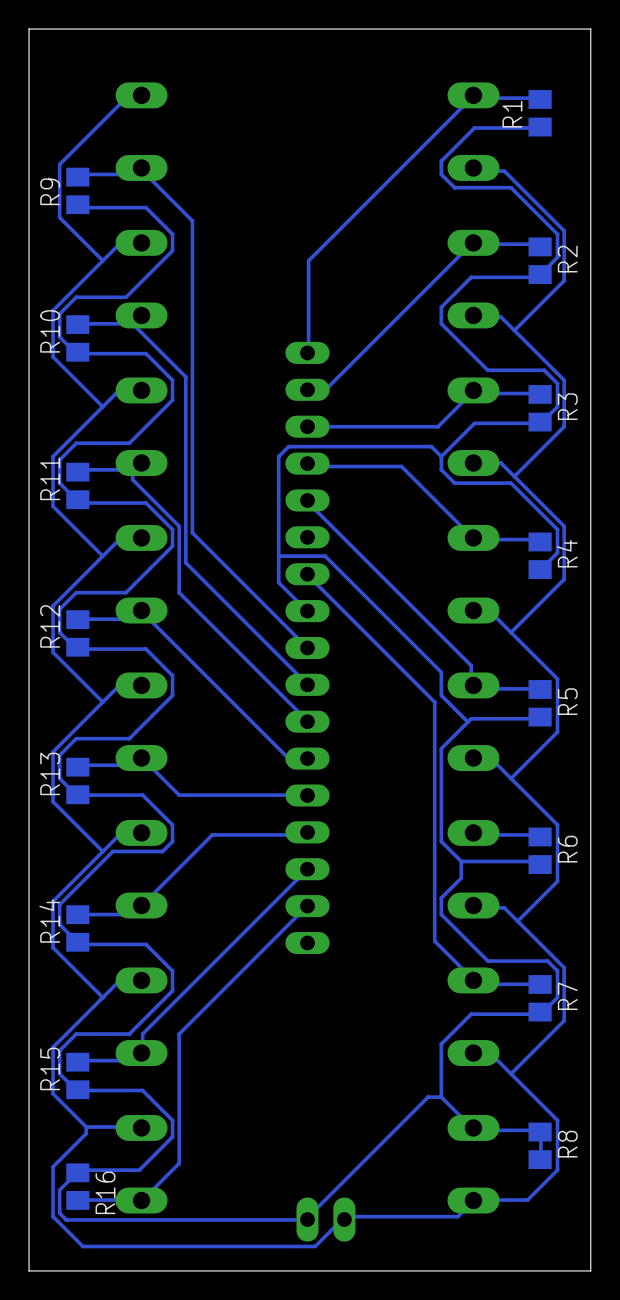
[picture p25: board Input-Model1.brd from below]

Board: 2 copper layers, 38.7 x 85.5 mm, 34 parts (16 on the bottom side), 17 nets.

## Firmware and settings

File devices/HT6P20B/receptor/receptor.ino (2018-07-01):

/* 
TITLE:       DECODER FOR HT6P20B ENCODER
CREATED BY:  AFONSO CELSO TURCATO
DATE:        18/JUN/2014
E-MAIL:      acturcato (at) gmail.com
LICENSE:     GPL
REV.:        04
DESCRIPTION:
http://acturcato.wordpress.com/2014/01/04/decoder-for-ht6p20b-encoder-on-arduino-board-english/
DESCRIÇÃO:
http://acturcato.wordpress.com/2013/12/20/decodificador-para-o-encoder-ht6p20b-em-arduino/
*/

const byte pinRF = 5;  // Pin where RF Module is connected. If necessary, change this for your project

int lambda;      // on pulse clock width (if fosc = 2KHz than lambda = 500 us)

struct rfControl        //Struct for RF Remote Controls
{
   unsigned long addr;  //ADDRESS CODE
   boolean btn1;        //BUTTON 1
   boolean btn2;        //BUTTON 2
};

boolean ACT_HT6P20B_RX(struct rfControl &_rfControl){ 
  
  static boolean startbit;      //checks if start bit was identified
  static int counter;           //received bits counter: 22 of Address + 2 of Data + 4 of EndCode (Anti-Code)
  static unsigned long buffer;  //buffer for received data storage
  
  int dur0, dur1;  // pulses durations (auxiliary)
  
  if (!startbit)
  {// Check the PILOT CODE until START BIT;
    dur0 = pulseIn(pinRF, LOW);  //Check how long DOUT was "0" (ZERO) (refers to PILOT CODE)
        
    //If time at "0" is between 9200 us (23 cycles of 400us) and 13800 us (23 cycles of 600 us).
    if((dur0 > 9200) && (dur0 < 13800) && !startbit)
    {    
      //calculate wave length - lambda
      lambda = dur0 / 23;
      
      //Reset variables
      dur0 = 0;
      buffer = 0;
      counter = 0;
      
      startbit = true;
    }
  }

  //If Start Bit is OK, then starts measure os how long the signal is level "1" and check is value is into acceptable range.
  if (startbit && counter < 28)
  {
    ++counter;
    
    dur1 = pulseIn(pinRF, HIGH);
    
    if((dur1 > 0.5 * lambda) && (dur1 < (1.5 * lambda)))  //If pulse width at "1" is between "0.5 and 1.5 lambda", means that pulse is only one lambda, so the data é "1".
    {
      buffer = (buffer << 1) + 1;   // add "1" on data buffer
    }
    else if((dur1 > 1.5 * lambda) && (dur1 < (2.5 * lambda)))  //If pulse width at "1" is between "1.5 and 2.5 lambda", means that pulse is two lambdas, so the data é "0".
    {
      buffer = (buffer << 1);       // add "0" on data buffer
    }
    else
    {
      //Reset the loop
      startbit = false;
    }
  }
  
  //Check if all 28 bits were received (22 of Address + 2 of Data + 4 of Anti-Code)
  if (counter==28) 
  { 
    // Check if Anti-Code is OK (last 4 bits of buffer equal "0101")
    if ((bitRead(buffer, 0) == 1) && (bitRead(buffer, 1) == 0) && (bitRead(buffer, 2) == 1) && (bitRead(buffer, 3) == 0))
    {     
      counter = 0;
      startbit = false;
      
      //Get ADDRESS CODE from Buffer
      _rfControl.addr = buffer >> 6;
      
      //Get Buttons from Buffer
       _rfControl.btn1 = bitRead(buffer,4);
       _rfControl.btn2 = bitRead(buffer,5);
 
      //Serial.print("Address: "); Serial.println(_rfControl.addr, HEX);
      //Serial.print("Button1: "); Serial.println(_rfControl.btn1, BIN);
      //Serial.print("Button2: "); Serial.println(_rfControl.btn2, BIN);
      //Serial.println();
      
      //If a valid data is received, return OK
      return true;
    }
    else
    {
      //Reset the loop
      startbit = false;
    }
  }
  
  //If none valid data is received, return NULL and FALSE values 
  _rfControl.addr = NULL;
  _rfControl.btn1 = NULL;
  _rfControl.btn2 = NULL; 
  
  return false;
}

void setup(){    
  pinMode(pinRF, INPUT);
  pinMode(13, OUTPUT);
  
  Serial.begin(9600);
}

void loop(){
  digitalWrite(13, digitalRead(pinRF));  //blink de onboard LED when receive something

  struct rfControl rfControl_1;    //Set variable rfControl_1 as rfControl type
  
  if(ACT_HT6P20B_RX(rfControl_1))
  {
    //If a valid data is received, print ADDRESS CODE and Buttons values    
    Serial.print("Address: "); Serial.println(rfControl_1.addr, HEX);
    Serial.print("Button1: "); Serial.println(rfControl_1.btn1, BIN);
    Serial.print("Button2: "); Serial.println(rfControl_1.btn2, BIN);
    Serial.println();
  }
}

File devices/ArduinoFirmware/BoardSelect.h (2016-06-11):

#ifndef BoardSelect_h
#define BoardSelect_h

// make sure exactly one of these lines is uncommented:
#define UNO
//#define NANO
//#define MEGA

const byte NUM_STRINGS = 0; // not implemented yet

const int MIN_ANALOG_INPUT = 0; // analog inputs
// 0 and 1 are serial port pins 
const int MIN_PIN_NUMBER = 2; // digital I/O
const int STATUS_LED_PIN = 13;
#ifdef UNO
  const int MAX_ANALOG_INPUT = 5;
  const int MAX_PROGRAM_SIZE = 750; // in bytes (includes the 34(?) header bytes)
  const int MAX_PIN_NUMBER = 12; // pin 13 is a status LED
  const int DEVICE_CONFIG_EEPROM_BYTES = 16;
  const int PWM_PINS[] = {3, 5, 6, 9, 10, 11};
  const int PWM_PIN_COUNT = 6; // must be length of the PWM_PINS array
  const int NUM_BOOLEANS = 512; // has to be a multiple of 8
  const byte NUM_NUMERICS = 24; // has to be a multiple of 8
#endif
#ifdef NANO
  const int MAX_ANALOG_INPUT = 7;
  const int MAX_PROGRAM_SIZE = 750; // in bytes (includes the 34(?) header bytes)
  const int MAX_PIN_NUMBER = 12; // pin 13 is a status LED
  const int DEVICE_CONFIG_EEPROM_BYTES = 16;
  const int PWM_PINS[] = {3, 5, 6, 9, 10, 11};
  const int PWM_PIN_COUNT = 6; // must be length of the PWM_PINS array
  const int NUM_BOOLEANS = 512; // has to be a multiple of 8
  const byte NUM_NUMERICS = 24; // has to be a multiple of 8
#endif
#ifdef MEGA
  const int MAX_ANALOG_INPUT = 15;
  const int MAX_PROGRAM_SIZE = 3750; // in bytes (includes the 34(?) header bytes)
  const int MAX_PIN_NUMBER = 53; // pin 13 is a status LED
  const int DEVICE_CONFIG_EEPROM_BYTES = 56;
  const int PWM_PINS[] = {2, 3, 4, 5, 6, 7, 8, 9, 10, 11, 12, 44, 45, 46};
  const int PWM_PIN_COUNT = 14; // must be length of the PWM_PINS array
  const int NUM_BOOLEANS = 1024; // has to be a multiple of 8
  const byte NUM_NUMERICS = 96; // has to be a multiple of 8
#endif

#endif

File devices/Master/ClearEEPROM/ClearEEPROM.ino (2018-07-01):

#include <Mouse.h>

/*
 * EEPROM Clear
 *
 * Sets all of the bytes of the EEPROM to 0.
 * Please see eeprom_iteration for a more in depth
 * look at how to traverse the EEPROM.
 *
 * This example code is in the public domain.
 */

#include <EEPROM.h>

void setup() {
  // initialize the LED pin as an output.
  pinMode(13, OUTPUT);
  
  /***
    Iterate through each byte of the EEPROM storage.

    Larger AVR processors have larger EEPROM sizes, E.g:
    - Arduno Duemilanove: 512b EEPROM storage.
    - Arduino Uno:        1kb EEPROM storage.
    - Arduino Mega:       4kb EEPROM storage.

    Rather than hard-coding the length, you should use the pre-provided length function.
    This will make your code portable to all AVR processors.
  ***/

  for (int i = 58 ; i < EEPROM.length() ; i++) {
    EEPROM.write(i, 0);
  }

  // turn the LED on when we're done
  digitalWrite(13, HIGH);
}

void loop() {
  /** Empty loop. **/
}

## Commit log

2016-02-18 Estrutura de base do controlador
2016-02-18 Testes de comunicação com a porta serial
2016-02-19 Testes de leitura do RXTX
2016-02-20 Adicionados os fontes originais para o arduino
2016-02-22 Alterações para a leitura da porta Serial
2016-02-26 Restaurando a versão original do arduino
2016-02-29 Implementados os comandos de comunicação com o Arduino
2016-03-29 Boxes para alocação do raspberry e arduinos
    [MEGA_R2_MOUNT.STL, Raspberry_Pi_B+_Sleeve_v1-1_CAP.STL, Raspberry_Pi_B+_Sleeve_v1-1_SOLID.STL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]
2016-04-04 Adicionadas as funcionalidades: - Parallel Series - Interpretação do JSON para programação
2016-04-04 Adicionada a programação de valores numericos (a concluir)
2016-04-13 Adicionadas as paredes para o suporte
    [SupportV2.fcstd]
2016-04-21 Alteraçoes da caixa
    [Relays.fcstd, SupportV2.fcstd]
2016-04-28 Adicionada a função de programação remota
    [Base.fcstd]
2016-05-01 Adicionadas as funcionalidades de FallingEdge e RisingEdge ao interpretador de JSON Ladder
2016-05-03 Adicionada a Caixa V3
    [SupportV3-Box.stl, SupportV3-Tampa.stl, SupportV3.fcstd]
2016-05-08 Adicionado o encaixe de parafuso para fixação
    [Encaixe-Parafuso.fcstd]
2016-05-12 Adicionado o projeto de inputs
    [Input-Model1.brd, Input-Model1.sch]
2016-05-19 Module configuration
    [4-Relay-Box.stl, 4-Relay-Cover.stl, Input-Model1.brd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]
2016-06-01 Melhorias nos processos de comunicação com o Arduino
    [Input-Model1.brd]
2016-06-11 Reviewing arduino communication protocols
2016-06-11 Major fixes and refactoring of device operations
2016-06-17 Added the device communication protocol documentation.
2016-06-25 Removed the mock-devices
2016-09-09 devices: Add counter implementation
2016-09-13 Added comparator to devices Changed NC and NO interpreters to their own classes
2016-09-18 Added Timers and Counters
2016-11-05 Added holes on relay box
    [SupportV3-Box.stl, SupportV3.fcstd]
2016-11-15 controller: adjusted .deb installer for full instalation on raspberry pi
2017-03-08 added capability for reading DS18B20 sensors
2017-03-08 Added DS18B20 sensors
